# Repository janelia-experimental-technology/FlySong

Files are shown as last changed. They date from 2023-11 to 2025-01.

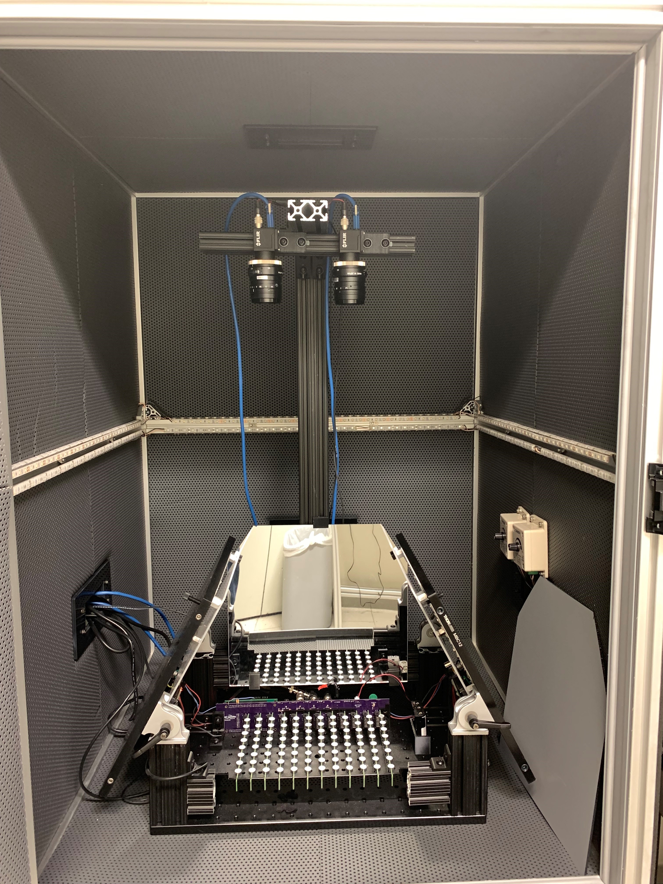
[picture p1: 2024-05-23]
PHOTOS/RIG WITH RGB/LEDrigall.jpg

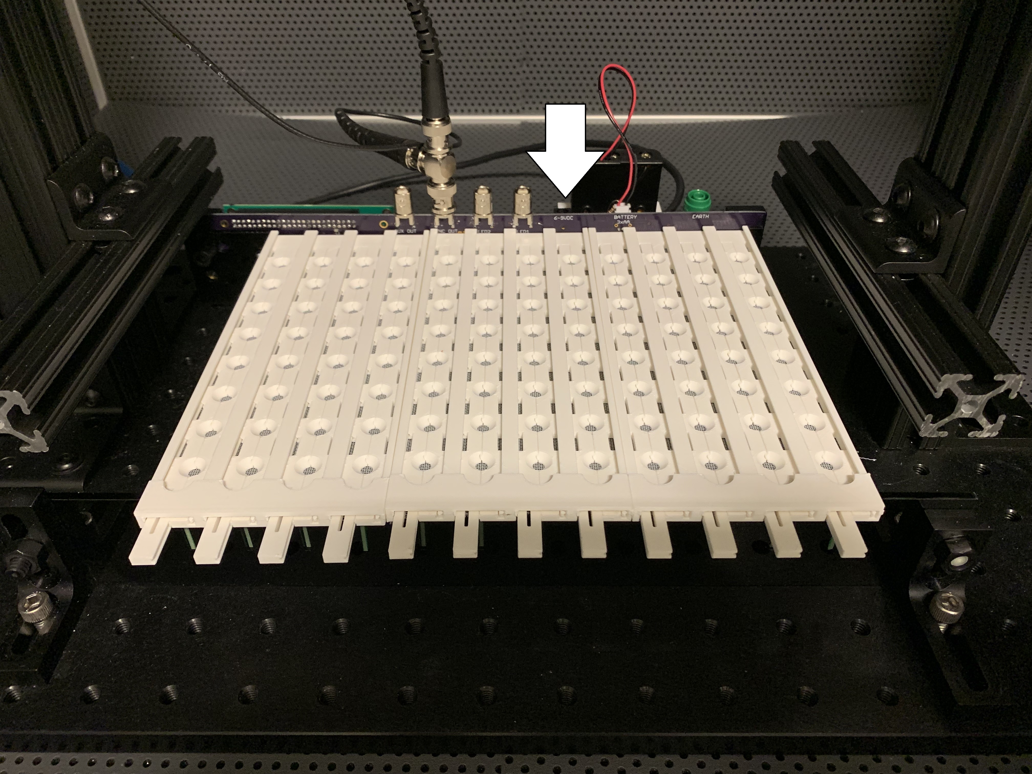
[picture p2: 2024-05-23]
PHOTOS/6V conector.jpg

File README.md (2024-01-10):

# FlySong
Song Torrent: A 96 Chamber Fly Courtship Recording Array.

[Preprint](https://www.biorxiv.org/content/10.1101/2024.01.09.574712v1)

The 96 Chamber Array and open-source software was designed to provide high throughput acquisition of Drosophila fly courtship songs. 
Up to 96 separate chambers can be recorded simultaneously along with temperature data for each chamber. Chambers are designed as three 
arrays of 32 chambers each and have sliding partitions to allow loading of separated males and females. The chambers can be top loaded
using a mouth pipette with a sliding cover and loading hole or bottom loaded through a slit in the lower mesh. The latter method could
be used by auto-loading systems. Two optogenetic light drivers are provided and their timing and brightness can be controlled. A camera 
frame trigger ouput is also provided. The software allows any number and arrangement of chambers to be recorded. A separate time and 
brightness comma-separated variable (CSV) file defines the optogenetic light pattern. A separate CSV file can be used to predefine the
individual sample names and their chamber locations, or this information can be entered interactively in the GUI and saved. All data 
and metadata (lights, temperatures, camera triggers, audio, sample information, etc.) are saved to .WAV files

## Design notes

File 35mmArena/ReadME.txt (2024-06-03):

35mmArena

The 35mm Arena provides a circular, 35mm diameter, fly arena with recording capbilities. Seven microphones provide coverage for the entire arena. The circuitry is the same design used in the 96 channel FlySong rig, so one 35mm arena can be plugged into one of the 96 channel backplane connectors and use the same software to record audio.

Boards available at Circuithub:

3MIC_backplaneREVA
3MIC_ximpedanceREVB

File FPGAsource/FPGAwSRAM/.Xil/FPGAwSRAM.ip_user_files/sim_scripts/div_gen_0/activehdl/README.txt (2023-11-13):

################################################################################
# Vivado (TM) v2017.1 (64-bit)
#
# README.txt: Please read the sections below to understand the steps required to
#             run the exported script and information about the source files.
#
# Generated by export_simulation on Sun May 14 15:33:39 -0400 2017
#
################################################################################

1. How to run the script:-

From the shell prompt in the current directory, issue the following command:-

./div_gen_0.sh

This command will launch the 'compile', 'elaborate' and 'simulate' functions
implemented in the script file for the 3-step flow. These functions are called
from the main 'run' function in the script file. For IES this command will
launch the 'execute' function for the single-step flow.

The 'run' function first executes 'setup' function the purpose of which is to
create simulator specific setup files, create design library mappings and library
directories and copy 'glbl.v' from the Vivado software install location into the
current directory.

The 'setup' function is also used for removing the simulator generated data in
order to reset the current directory to the original state when export_simulation
was launched. This generated data can be removed by specifying the '-reset_run'
switch to the './div_gen_0.sh' script.

./div_gen_0.sh -reset_run

To keep the generated data from the previous run but regenerate the setup files
and library directories, use the -noclean_files switch.

./div_gen_0.sh -noclean_files

For more information on the script, please type './div_gen_0.sh -help'.

2. Additional design information files:-

export_simulation generates following additional files that can be used for
fetching the design files information or for integrating with external custom
scripts.

Name   : file_info.txt
Purpose: This file contains detail design file information based on the compile
         order when export_simulation was executed. The file contains information
         about the file type, name, whether belongs to IP, associated library and
         the file path.

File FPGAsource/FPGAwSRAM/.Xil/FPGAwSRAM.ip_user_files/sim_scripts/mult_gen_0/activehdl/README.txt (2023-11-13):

################################################################################
# Vivado (TM) v2017.1 (64-bit)
#
# README.txt: Please read the sections below to understand the steps required to
#             run the exported script and information about the source files.
#
# Generated by export_simulation on Sun May 14 15:33:40 -0400 2017
#
################################################################################

1. How to run the script:-

From the shell prompt in the current directory, issue the following command:-

./mult_gen_0.sh

This command will launch the 'compile', 'elaborate' and 'simulate' functions
implemented in the script file for the 3-step flow. These functions are called
from the main 'run' function in the script file. For IES this command will
launch the 'execute' function for the single-step flow.

The 'run' function first executes 'setup' function the purpose of which is to
create simulator specific setup files, create design library mappings and library
directories and copy 'glbl.v' from the Vivado software install location into the
current directory.

The 'setup' function is also used for removing the simulator generated data in
order to reset the current directory to the original state when export_simulation
was launched. This generated data can be removed by specifying the '-reset_run'
switch to the './mult_gen_0.sh' script.

./mult_gen_0.sh -reset_run

To keep the generated data from the previous run but regenerate the setup files
and library directories, use the -noclean_files switch.

./mult_gen_0.sh -noclean_files

For more information on the script, please type './mult_gen_0.sh -help'.

2. Additional design information files:-

export_simulation generates following additional files that can be used for
fetching the design files information or for integrating with external custom
scripts.

Name   : file_info.txt
Purpose: This file contains detail design file information based on the compile
         order when export_simulation was executed. The file contains information
         about the file type, name, whether belongs to IP, associated library and
         the file path.

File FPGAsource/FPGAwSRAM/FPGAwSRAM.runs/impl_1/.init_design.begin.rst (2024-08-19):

<?xml version="1.0"?>
<ProcessHandle Version="1" Minor="0">
    <Process Command=".planAhead." Owner="sawtelles" Host="SAWTELLES-LW2" Pid="19712">
    </Process>
</ProcessHandle>

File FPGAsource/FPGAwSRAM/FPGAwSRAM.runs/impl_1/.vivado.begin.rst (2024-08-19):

<?xml version="1.0"?>
<ProcessHandle Version="1" Minor="0">
    <Process Command="vivado.bat" Owner="sawtelles" Host="SAWTELLES-LW2" Pid="18224" HostCore="20" HostMemory="033947738112">
    </Process>
</ProcessHandle>

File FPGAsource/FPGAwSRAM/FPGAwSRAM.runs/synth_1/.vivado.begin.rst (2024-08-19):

<?xml version="1.0"?>
<ProcessHandle Version="1" Minor="0">
    <Process Command="vivado.bat" Owner="sawtelles" Host="SAWTELLES-LW2" Pid="8160" HostCore="20" HostMemory="033947738112">
    </Process>
</ProcessHandle>

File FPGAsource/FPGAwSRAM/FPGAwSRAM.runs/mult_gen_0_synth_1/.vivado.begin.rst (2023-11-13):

<?xml version="1.0"?>
<ProcessHandle Version="1" Minor="0">
    <Process Command="vivado.bat" Owner="sawtelles" Host="SAWTELLES-LW1" Pid="9176">
    </Process>
</ProcessHandle>

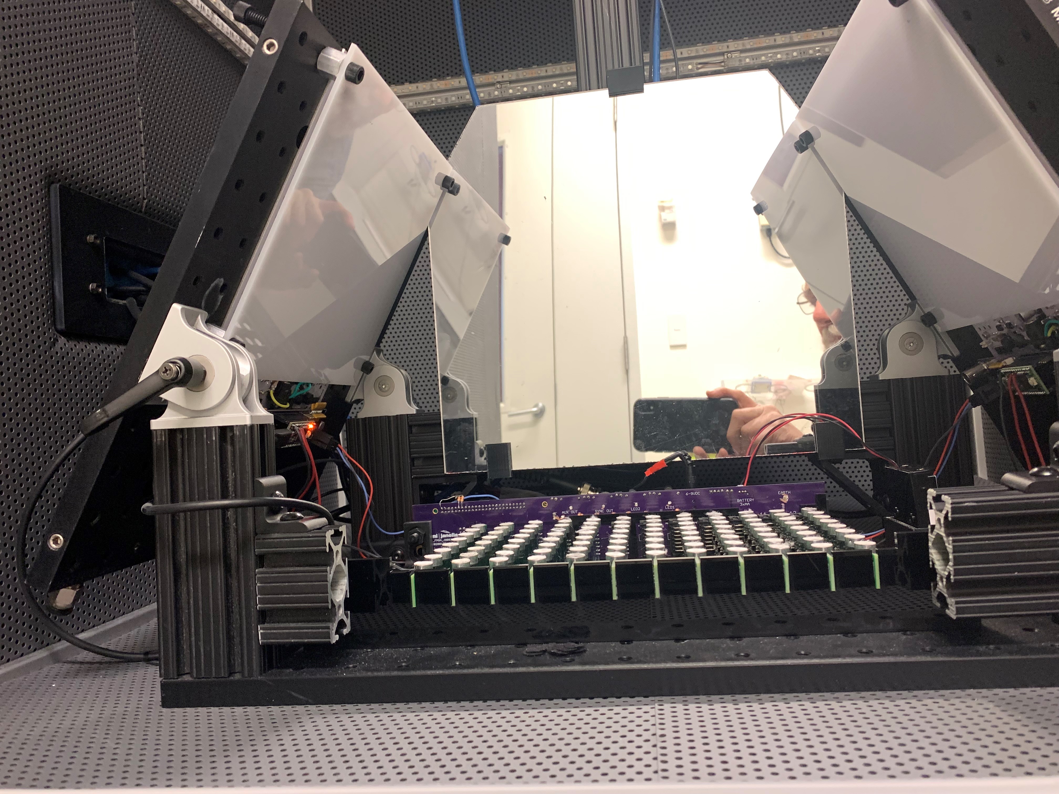
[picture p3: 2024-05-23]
PHOTOS/RIG WITH RGB/LEDrigfront.jpg

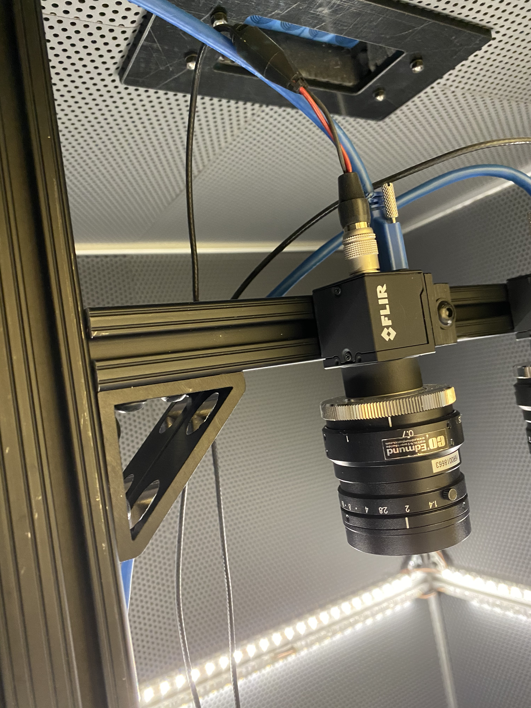
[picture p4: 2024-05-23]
PHOTOS/camera.jpg

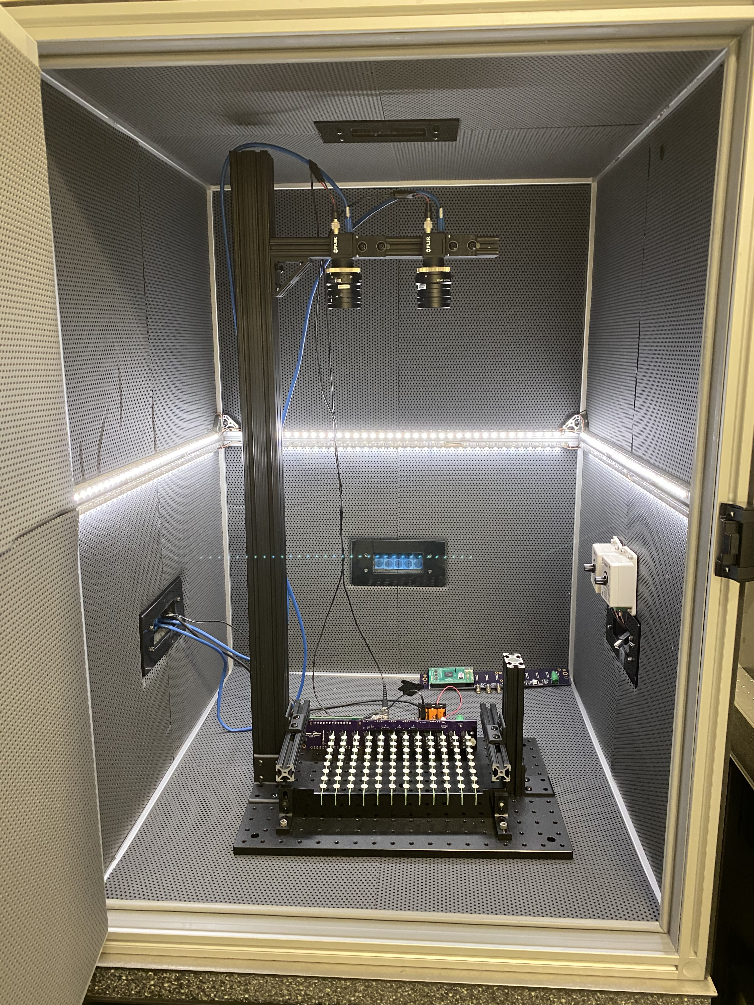
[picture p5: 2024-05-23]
PHOTOS/rig.jpg

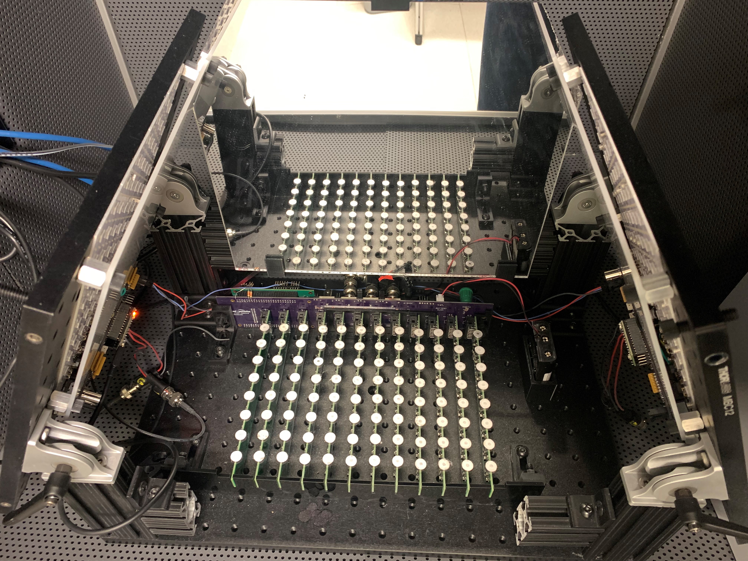
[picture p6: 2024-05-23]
PHOTOS/RIG WITH RGB/LEDrigFromRear.jpg

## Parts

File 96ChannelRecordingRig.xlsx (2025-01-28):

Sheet: Top Level
Top level | Fly Courtship 96 Channel Recording Rig
Quantity | Function | Item | Manufacturer | Man. Part Number | Vendor | Vendor Part Number | Cost | Total Cost | Notes
1 | Breadboard | Aluminum Breadboard 12" x 18" x 1/2", 1/4"-20 Taps | Thorlabs | MB1218 | (same) | (same) | $188.00 | $188.00
4 | backplane to breadboard bracket | Slim Right-Angle Bracket with Counterbored Slots | Thorlabs | AB90H | (same) | (same) | $27.04 | $108.16 | OR - use backplaneBracket 3-D print
 |  | Backplane Bracket | 3-D print |  |  | backplaneBracket |  | $0.00 | alternate to AB90H
1 | Fasten bracketss to breadboard | Black-oxide stainless steel screw 1/4-20 x 5/8 |  |  | McMaster-Carr | 96006A705 | $8.05 | $8.05 | pkg of 25 - need 4
1 | Fasten backplane and board supports to brackets | Nylon Socket Head Screws, black, 1/4"-20 Thread Size, 7/8" Long |  |  | McMaster-Carr | 95868A745 | $9.57 | $9.57 | pkg of 100, need 4
1 | Fasteners for nylon screws | Nylon Hex Nut, 1/4"-20 Thread Size |  |  | McMaster-Carr | 95868A743 | $9.65 | $9.65 | pkg of 100 need 4
1 | Camera Support Post | T-Slotted Framing, Quad Rail, Black 2" High x 2" Wide, Solid |  |  | McMaster-Carr | 47065T678 | $59.62 | $59.62 | Only for standard (non-RGB-IR) setup
2 | Camera Post Brackets | T-Slotted Framing, Black Open Gusset Corner Bracket for 2" High Rail, 2" Long |  |  | McMaster-Carr | 3136N183 | $25.34 | $50.68
1 | Camera Mounting Bar | T-Slotted Framing, Double Six Slot Rail, Black, 2" High x 1" Wide, Solid |  |  | McMaster-Carr | 47065T495 | $17.24 | $17.24 | 12" length
1 | Chamber supports | MicrophoneChamberSupports_J007968.dxf | Janelia | J007968 | McMaster-Carr | 8505K741 | $7.71 | $7.71 | Laser cut from 1/8" acrylic
1 | Battery Box | BatteryBox_J007969.stl | Janelia | J007969 |  |  | $0.00 | $0.00 | 3D print
1 | Battery Holder | BATT HOLDER AA 3 CELL WIRE LEADS | Keystone Electronics | 2465CN | Digi-Key | 36-2465CN-ND | $2.20 | $2.20
1 | Charger with 4 batteries | BATT CHARGER WALL MT 300MA/150MA | Energizer Battery Company | CHVCMWB-4 | Digi-Key | N732-ND | $18.46 | $18.46
8 | Batteries | BATTERY NIMH 1.2V 2.3AH AA 1=8PK | Energizer Battery Company | NH15BP-8 | Digi-Key | N730-ND | $3.98 | $31.84 | optional, gives 4 changes of batteries
1 | FPGA Board | XC7A15T Xilinx Artix-7, 32 Mb SPI flash | Opal Kelly | XEM7001 | Opal Kelly | (same) | $199.95 | $199.95
1 | Power Supply | AC/DC WALL MNT ADAPTER 6V 200MA | Triad Magnetics | WDU6-200 | Digi-Key | 237-2322-ND | $8.38 | $8.38
1 | Headers for FPGA board | Female header connectors for XEM3/6/7001 | Opal Kelly | HDRM-XEM3001 | Opal Kelly | (same) | $10.00 | $10.00 | Solder to bottom of XEM7001
3 | Fly Chamber Assembly | FLY CHAMBER ASSEMBLY TAB |  |  |  |  |  | $0.00 | 3 pieces
1 | Backplane interconnection board | BACKPLANE PCB ASSEMBLY TAB |  | 12_BCKPLN_FPGA_J007922REVA |  |  | $99.49 | $99.49
12 | Microphone Amplifiers/Converters | MICROPHONE PCB ASSEMBLY TAB |  | 8MIC_ximpedance_J007901A |  |  | $212.14 | $2545.68 | 12 pieces
2 | Camera Assemblies | CAMERA ASSEMBLY TAB |  |  |  |  | $3158.38 | $6316.76
 | Opal Kelley FPGA Drivers |  | Opal Kelly | FrontPanelUSB-DriverOnly-5.3.0.exe |  |  |  | $0.00
 | Fly Song Software |  | Janelia | FlySong.zip |  |  |  | $0.00
1 | RGB_IR Lighting | RGB_IR LIGHTING TAB |  |  |  |  | $2189.02 | $2189.02 | optional if optogenic and/or IR lighting is needed
 | TOTAL |  |  |  |  |  |  | $11880.46

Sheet: Camera Assembly
Camera Assembly
Quantity | Value | Device | Manufacturer | Manufacturer PN | Vendor | Vendor PN | $ea | $Total | Notes
2 | Blackfly S Monochrome | Camera | FLIR | BFS-U3-200S6M-C | Edmund Optics | 11-521 | $850.00 | $1700.00
2 | 50mm 1" Sensor Format C-Mount | Lens |  |  | Edmund Optics | 63-248 | $595.00 | $1190.00
2 | Type-A to Micro-B, USB 3.1 Locking Cable, 3m | USB Cable |  |  | Edmund Optics | 86-770 | $52.00 | $104.00
2 | Blackfly S/Blackfly 6-pin GPIO Hirose Connector Cable, 1m | Trigger Cable |  |  | Edmund Optics | 88-064 | $67.00 | $134.00
2 | 5.9" (149.86mm) BNC, Male Plug To Wire Lead Test Lead 500VAC | BNC Assembly | Pomona | 4970 | Digi-Key | 501-1031-ND | $15.19 | $30.38
 | Trigger Cable Assembly Instructions |  | Janelia | TriggerCable.sch |  |  |  |  | Instructions to wire cable
 | TOTAL |  |  |  |  |  |  | $3158.38

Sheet: RGB-IR Lighting
 |  |  |  |  |  |  |  |  |  | 2x2 Framing |  | 1x2 Framing
Quantity | Value | Device | Manufacturer | Manufacturer Part Number | Vendor | Vendor PN | $ea | $ total | Notes | Length | Total Length | Length | Total Length | $ea | $Total | DNI | Substitutions Allowed | Substitute Manufacturer | Substitute Part Number
2 | 7x7 RGB-IR LED Board | Janelia LED Board |  |  |  |  | $298.76 | $597.51
2 | 7x7 controller |  |  |  |  |  | $90.11 | $180.22
2 | 12" x 12" Breadboard | Aluminum Breadboard 12" x 12" x 1/2", 1/4"-20 Taps | Thorlabs | MB12 |  |  | $172.40 | $344.80 | MBC12 if active cooling needed
54 | Thread adapter | Adapter with Internal 4-40 Threads and External 1/4"-20 Thread | Thorlabs | AE4E25E |  |  | 4.97 | $268.38
2 | Diffuser |  | ePlastics | 2447 White 1/18" thick |  |  |  | $0.00 | Laser cut using DiffuserFlySongRGB.dxf
4 | Locking Pivot | T-Slotted Framing, Locking Inline/Perpendicular Pivot for 2" Double/Quad | McMaster-Carr | 47065T381 |  |  | $49.83 | $199.32
2 | Vertical Post-front | T-Slotted Framing, Double Six Slot Rail, Black, 2" High x 1" Wide, Solid | McMaster-Carr | 47065T495 |  |  |  | $0.00 | Cut to 4.5" length |  |  | 4.5 | 9
2 | Vertical Post-rear | T-Slotted Framing, Double Six Slot Rail, Black, 2" High x 2" Wide, Solid | McMaster-Carr | 47065T678 |  |  |  | $0.00 | Cut to 4.5" length | 4.5 | 9
3 | 1x2 Right Angle Bracket | T-Slotted Framing, Black Corner Bracket, 1" Long for 2" High Double/Quad Rail | McMaster-Carr | 47065T474 |  |  | $16.60 | $49.80
1 | Cross Beam | T-Slotted Framing, Double Six Slot Rail, Black, 2" High x 2" Wide, Solid | McMaster-Carr | 47065T678 |  |  |  | $0.00 | Cut to 14" length | 14 | 14
1 | Camera Post | T-Slotted Framing, Double Six Slot Rail, Black, 2" High x 2" Wide, Solid | McMaster-Carr | 47065T695 |  |  |  | $0.00 | Cut to 28" length | 28 | 28
1 | Camera Beam | T-Slotted Framing, Double Six Slot Rail, Black, 2" High x 1" Wide, Solid | McMaster-Carr | 47065T695 |  |  |  | $0.00 | Cut to 7" length |  |  | 7 | 7
1 | Camera Mount Beam | T-Slotted Framing, Double Six Slot Rail, Black, 2" High x 1" Wide, Solid | McMaster-Carr | 47065T496 |  |  |  | $0.00 | Cut to 12" length |  |  | 12 | 12
6 | 2x2 Brackets | T-Slotted Framing, Black Open Gusset Corner Bracket for 2" High Rail, 2" Long | McMaster-Carr | 3136N183 |  |  | $25.34 | $152.04
2 | Mirrors | Acrylic Plastic Damage-Resistant Mirror, 12" High x 12" Wide x 1/8" Thick, Screw Mount | McMaster-Carr | 3052K19 |  |  | $25.00 | $50.00 | Laser Cut using FlySongRGBMirror.dxf
2 | Front Miror Support | T-Slotted Framing, Double Six Slot Rail, Black, 2" High x 1" Wide, Solid | McMaster-Carr | 47065T495 |  |  |  | $0.00 | Cut to 2" length |  |  | 2 | 4
2 | Mirror Support Brackets | Black Corner Bracket, 1" Long, for 1" High Rail T-Slotted Framing | McMaster-Carr | 47065T831 |  |  | $9.71 | $19.42
4 | Diffuser Standoff | Male-Female Threaded Hex Standoff, Aluminum, 1/2" Hex Size, 1" Long, 1/4"-20 Thread Size | McMaster-Carr | 93505A197 |  |  |  | $0.00
2 | Rear Mirror Supports | 3-D printed |  | T-Slotted Mirror Support.stl |  |  |  | $0.00 | 3-D print
2 | Serial cable assembly | RGB Interconnect Cable |  |  |  |  |  | $0.00
2 | Power Supply | Desktop AC Adapters, Level VI, Desktop, 100 Watt, 90-264VAC Input, 28VDC Output, | Cincon | TRH100A280-12E13-Level-VI |  |  | $49.41 | $98.82
 |  |  |  |  |  |  |  | $0.00 | Total length |  | 51 |  | 32
 |  |  |  |  |  |  |  | $0.00
1 | TOTAL length needed | T-Slotted Framing, Double Six Slot Rail, Black, 2" High x 2" Wide, Solid | McMaster-Carr | 47065T678 |  |  | $96.65 | $96.65 |  |  | 51
3 | TOTAL length needed | T-Slotted Framing, Double Six Slot Rail, Black, 2" High x 1" Wide, Solid | McMaster-Carr | 47065T495 |  |  | $44.02 | $132.06 |  |  |  |  | 32
 |  |  |  |  |  | TOTAL |  | $2189.02

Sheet: Fly Chamber Assembly
Fly Chamber Assembly
Quantity | Function | Item | Manufacturer | Man. Part Number | Vendor | Vendor Part Number | Cost | Total Cost | Notes | Manufacturing File
3 | Fly Chambers (4x8) | Fly Chamber Base, 32 chambers | Janelia | Chamber_4x8_J007977 |  |  |  |  | 3D Print | Chamber_4x8_J007977.STL
12 | Chamber -moving half | Fly Chamber Sliding part, 8 chambers | Janelia | ChamberSlide_J007974 |  |  |  |  | 3D Print | ChamberSlide_J007974.STL
2 | Loading Slide | Fly Chamber Fly loader | Janelia | Loader_J007975 | McMaster-Carr | 8560K171 (raw material) | 5.61 |  | laser cut, 1/16" clear acrylic | Loader_J007975.dxf
12 | Run Slide | Fly Chamber Run Slide cover | Janelia | RunSlide_J007976 | McMaster-Carr | 8560K171 (raw material) | 5.61 |  | laser cut, 1/16" clear acrylic | RunSlide_J007976.dxf
1 | Plastic Mesh | Moisture-Resistant Plastic Mesh, 34 x 34 Mesh Size, 53" Wide |  |  | McMaster-Carr | 9318T21 | 20.21 |  | heat melt to bottom of chamber body

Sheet: Backplane Assembly
Backplane | 12_BCKPLN_FPGA_J007922REVA
Quantity | Value | Device | Designators | Manufacturer | Manufacturer Part Number | Vendor | Vendor Part Number | $ea | $Total | DNI | Substitutions Allowed | Substitute Manufacturer | Substitute Part Number
1 |  | CONN BANANA JACK SOLDER GREEN | P13 | Cal Test Electronics | CT3151-5 | Digi-Key | BKCT3151-5-ND | $2.05 | $2.05 |  | yes
1 |  | CONN HEADER R/A 3POS 2MM | J1 | Keystone Electronics | 975 | Digi-Key | 36-975-ND | $1.12 | $1.12 |  | yes
1 | header | CONN HEADER VERT 4POS 2.54MM | JP1 | Wurth Electronics Inc. | 61300411121 | Digi-Key | 732-5317-ND | $0.18 | $0.18 |  | yes
1 |  | CONN PWR JACK 2X5.5MM SOLDER | J2 | CUI Inc. | PJ-002AH-SMT-TR | Digi-Key | CP-002AHPJCT-ND | $1.44 | $1.44 |  | yes
10 | 0.1 | CAPS0603S | C1 C2 C3 C4 C5 C6 C7 C8 C11 C12 | KEMET | C0603C104K5RACTU | DigiKey | 399-5089-1-ND | $0.21 | $2.10 |  | yes
2 | 2G240 | IC BUFFER INVERT 5.5V SM8 | U7 U8 | Texas Instruments | SN74LVC2G240DCTR | Digi-Key | 296-15588-1-ND | $0.72 | $1.44 |  | yes
2 | 10 | CAP CER 10UF 16V X7R 1210 | C9 C10 | KEMET | C1210C106K4RACTU | Digi-Key | 399-8225-1-ND | $0.65 | $1.30 |  | yes
8 | 49.9 | RES 49.9 OHM 1% 1/8W 0805 | R3 R4 R6 R7 R8 R9 R10 R11 | Stackpole Electronics Inc | RMCF0805FT49R9 | Digi-Key | RMCF0805FT49R9CT-ND | $0.10 | $0.80 |  | yes
3 | 74LVC1G17DBV | IC BUF NON-INVERT 5.5V SOT23-5 | U1 U2 U3 | Texas Instruments | SN74LVC1G17QDBVRQ1 | Digi-Key | 296-32300-1-ND | $0.36 | $1.08 |  | yes
2 | 191 | RES 100 OHM 1% 1/8W 0805 | R1 R5 | Stackpole Electronics Inc | RMCF0805FT191R | Digi-Key | RMCF0805FT191RCT-ND | $0.10 | $0.20 |  | yes
1 | 200K | RES 200K OHM 1% 1/8W 0805 | R13 | Stackpole Electronics Inc | RMCF0805FT200K | Digi-Key | RMCF0805FT200KCT-ND | $0.10 | $0.10 |  | yes
1 | 100K | RES 100K OHM 1% 1/8W 0805 | R13 | Stackpole Electronics Inc | RMCF0805FT100K | Digi-Key | RMCF0805FT100KCT-ND | $0.10 | $0.10 |  | yes
4 | BNC | CONN BNC JACK STR 50 OHM PCB | J3 J4 J5 J6 | TE Connectivity AMP Connectors | 5227699-3 | Digi-Key | A32249-ND | $4.77 | $19.08 |  | yes
12 | CON14ST2X7_PLUG | CONN HDR 14POS 0.1 GOLD PCB | P1 P2 P3 P4 P5 P6 P7 P8 P9 P10 P11 P12 | Sullins Connector Solutions | SFH11-PBPC-D07-ST-BK | Digi-Key | S9195-ND | $0.91 | $10.92 |  | yes
1 | LP2950CDT-5.0 | IC REG LINEAR 5V 100MA TO252-3 | U6 | Texas Instruments | LP2950CDT-5.0 | Digi-Key | LP2950CDT-5.0/NOPB-ND | $1.28 | $1.28 |  | yes
1 | MAX931 | IC COMP SNGL LOW PWR W/REF 8SOIC | U2 | Maxim Integrated | MAX931ESA+T | Digi-Key | MAX931ESA+TCT-ND | $5.40 | $5.40 |  | yes
2 | TLP176G(F) | SSR RELAY SPST-NO 2A 0-40V | U5 U9 | Toshiba Semiconductor and Storage | TLP241A(TP1,F | Digi-Key | TLP241A(TP1FCT-ND | $2.18 | $4.36 |  | yes
2 | header 2x25 | CONN HDR 50POS 0.1 GOLD PCB | M1 | Sullins Connector Solutions | PPPC252LFBN-RC | Digi-Key | S7128-ND | $2.64 | $5.28 |  | yes
1 | header 2x10 | CONN HDR 20POS 0.1 GOLD PCB | M1 | Sullins Connector Solutions | PPPC102LFBN-RC | Digi-Key | S6106-ND | $1.26 | $1.26 |  | yes
1 | PCB | Bare Printed Circuit Board |  | Janelia | 12_BCKPLN_FPGA_J007922REVB | Oshpark | https://oshpark.com/shared_projects/Ftha9rSP | $40.00 | $40.00
 |  |  |  |  |  |  | TOTAL |  | $99.49

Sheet: Microphone Assembly
Microphone |  | 8MIC_ximpedance_J007901A
Quantity | Value | Device | Designators | Manufacturer | Manufacturer Part Number | Vendor | Vendor Part Number | $ea | $Total | DNI | Substitutions Allowed | Substitute Manufacturer | Substitute Part Number
8 | 0 | RESISTOR_SM0603S | R58 R59 R60 R61 R62 R63 R65 R66 | Vishay Dale | CRCW06030000Z0EAHP | DigiKey | 541-0.0SBCT-ND | $0.16 | $1.28 |  | yes
11 | 0.1 | CAPS0603S | C1 C2 C3 C4 C5 C6 C7 C8 C87 C88 C98 | KEMET | C0603C104K5RACTU | DigiKey | 399-5089-1-ND | $0.21 | $2.31 |  | yes
9 | 0.01 NPO | CAP CER 10000PF 25V C0G/NP0 0603 | C10 C19 C20 C21 C22 C23 C24 C25 C26 | KEMET | C0603C103J3GACTU | DigiKey | 399-7838-1-ND | $0.45 | $4.05 |  | yes
~~0~~ | ~~DNI~~ | ~~CAPS0603S~~ | ~~C89 C90 C91 C92 C93 C94 C95 C96~~ |  |  |  |  |  | $0.00 | DNI
8 | 0.22 | 0.22µF Film Capacitor 12V 16V Acrylic, Metallized 1206 | C43 C44 C45 C46 C47 C48 C49 C50 | Cornell Dubilier | FCA1206C224M-H1 | DigiKey | 338-2774-1-ND | $0.78 | $6.24 |  | yes
16 | 0.047 | CAP CER 0.047UF 25V NP0 0805 | C52 C53 C54 C55 C56 C57 C58 C59 C79 C80 C81 C82 C83 C84 C85 C86 | KEMET | C0805C473K3GAC7800 | DigiKey | 399-14611-1-ND | $0.94 | $15.04 |  | yes
8 | 2.2 | CAP FILM 2.2UF 20% 25VDC 1210 | C35 C36 C37 C38 C39 C40 C41 C42 C77 | Rubycon | 25MU225MB23225 | DigiKey | 1189-2524-1-ND | $5.44 | $43.52 |  | yes
4 | 10 | CAP CER 10UF 25V X5R 0805 | C9 C51 C78 C97 | Murata | GRM21BR61E106KA73L | DigiKey | 490-5523-1-ND | $0.54 | $2.16 |  | yes
8 | 330p | CAP CER 330PF 50V C0G/NP0 0805 | C62 C64 C65 C66 C67 C68 C69 C70 | KEMET | C0805C331J1GACTU | DigiKey | 399-1131-1-ND | $0.21 | $1.68 |  | yes | AVX | 08055A331JAT2A
8 | 29K4 | RES SMD 29.4K OHM 1% 1/10W 0603 | R34 R35 R36 R37 R38 R39 R40 R41 | Susumu | RR0816P-2942-D-46C | DigiKey | RR08P29.4KDCT-ND | $0.10 | $0.80 |  | yes
25 | 49K9 | RES 49.9K OHM 0.1% 1/8W 0603 | R1 R18 R19 R20 R21 R22 R23 R24 R25 R26 R27 R28 R29 R30 R31 R32 R33 R43 R44 R45 R47 R48 R50 R51 R53 | Vishay Dale | TNPW060349K9BEEA | DigiKey | TNP49.9KAACT-ND | $0.59 | $14.75 |  | yes
8 | 4K02 | RES 4.02K OHM 0.1% 1/8W 0603 | R4 R5 R6 R7 R8 R9 R15 R17 | Vishay Dale | TNPW06034K02BEEA | DigiKey | TNP4.02KAACT-ND | $0.59 | $4.72 |  | yes
16 | 1200p | 1200pF Film Capacitor 100V Polyester, | C27 C28 C29 C30 C31 C32 C33 C34 C60 C61 C71 C72 C73 C74 C75 C76 | Panasonic | ECW-U1122JX5 | DigiKey | PCF1349CT-ND | $0.68 | $10.88 |  | yes
1 | 2514-5 | 14 Positions Header, Shrouded Connector 0.100" (2.54mm) Through Hole, Right Angle Gold | J1 | 3M | N2514-5002-RB | DigiKey | MHE14K-ND | $2.07 | $2.07
1 | LP3985 | IC REG LINEAR 3.3V 150MA SOT23-5 | U9 | Texas Instruments | LP3985IM5-3.3/NOPB | DigiKey | LP3985IM5-3.3/NOPBCT-ND | $0.66 | $0.66
1 | LTC1867L | 16 Bit Analog to Digital Converter 8 Input 1 SAR 16-SSOP | U18 | LT | LTC1867LACGN#PBF | DigiKey | LTC1867LACGN#PBF-ND | $18.47 | $18.47
8 | OPA2376 | General Purpose Amplifier 1 Circuit Rail-to-Rail 8-uMAX | U10 U11 U12 U13 U14 U15 U16 U17 | TI | OPA2376AIDGKR | DigiKey | 296-22630-1-ND | $2.29 | $18.32
8 | TMP05/06 | SENSOR DIGITAL -40C-150C SOT23-5 | U1 U2 U3 U4 U5 U6 U7 U8 | TI | TMP05BRTZ-500RL7 | DigiKey | TMP05BRTZ-500RL7CT-ND | $2.73 | $21.84
8 | 133K | RES SMD 133K OHM 1% 1/8W 0603 | R42 R46 R49 R52 R54 R55 R56 R57 | TE | CPF0603F133KC1 | DigiKey | A102212CT-ND | $0.18 | $1.44 |  | yes
9 | 47uF | CAP TANT 47UF 10% 10V 1206 | C11 C12 C13 C14 C15 C16 C17 C18 C63 | AVX Corporation | F931A476KAA | DigiKey | 478-8223-1-ND | $0.81 | $7.29 |  | yes
8 | 499 | RES 499 OHM 1% 1/8W 0603 | R2 R3 R10 R11 R12 R13 R14 R16 | Stackpole Electronics Inc | RNCP0603FTD499R | DigiKey | RNCP0603FTD499RCT-ND | $0.10 | $0.80 |  | yes
1 | 10 | RES 10 OHM 1% 1/8W 0603 | R64 | Stackpole Electronics Inc | RNCP0603FTD10R0 | DigiKey | RNCP0603FTD10R0CT-ND | $0.10 | $0.10 |  | yes
1 |  | Bare Printed Circuit Board |  | Janelia | 8MIC_ximpedance_J007901D | Oshpark | https://oshpark.com/shared_projects/GOl5GIfq | $15.00 | $15.00 |  |  | Other PCB vendors can be used
8 |  | Multilayer Ceramic Capacitor, 0.1 uF, 50 V, ± 10%, X7R, 0805 | C1 C2 C3 C4 C5 C6 C7 C8 | Samsung | CL21B104KBCNNNC | DigiKey | 1276-1003-1-ND | $0.10 | $0.80
8 | MIC-CUI | MIC COND ANALOG NOISE CAN -47DB | M1 M2 M3 M4 M13 M14 M15 M16 | CUI Inc. | CMP-5247TF-K | DigiKey | 102-1729-ND | $2.24 | $17.92 |  |  | Install after boards are assembled, using heat sink jig
Tools and fixtures |  |  |  |  |  |  |  |  | $212.14
 |  | Board alignment tool for microphone soldering |  | Janelia | mic_solder_station_holder_J007970.stl |  |  |  |  |  |  | 3D print, Place on microphone solder heat sink
 |  | Heat sink for microphone soldering |  | Janelia | mic_solder_station_J007971.ipt |  |  |  |  |  |  | Machine from aluminum

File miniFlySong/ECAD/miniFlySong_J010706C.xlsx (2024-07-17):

miniFlySong_J010706C.sch
Qty | Value | Device | Designators | Manufacturer | Man PN | Vendor | Vendor PN | $ea | $Total | Notes
1 |  | Connector Header Through Hole 4 position 0.100" (2.54mm) | GND | Würth Elektronik | 61300411121 | DK | 732-5317-ND | $0.19 | $0.19
1 |  | LED4045 red | BAD | Inolux | IN-S85CS5R | DK | 1830-IN-S85CS5RCT-ND | 0.27
1 |  | LED GREEN CLEAR SMD R/A | OK | Inolux | IN-S85CS5G | DK | 1830-IN-S85CS5GCT-ND | 0.36
2 | 0.1 | CAP CER 0.1UF 16V X7R 0603 | C1 C2 | KEMET | C0603C104K4RAC7082 | DK | 399-C0603C104K4RAC7082CT-ND | $0.10 | $0.20
1 | 74AUC1G17DBV | IC BUFF NON-INVERT 2.7 V SOT23-5 | U2 | Texas Instruments | SN74AUC1G17DBVR | DK | 296-12654-1-ND | $0.48 | $0.48
1 | 100K | RESISTOR_SM0805S | R1 | Bourns Inc. | CR0805AFX-1003EAS | DK | CR0805AFX-1003EASCT-ND | $0.10 | $0.10
3 | 191 | RESISTOR_SM0805S | R3 R5 R7 | Bourns Inc. | CR0805-FX-1910ELF | DK | 118-CR0805-FX-1910ELFCT-ND | $0.10 | $0.30
1 | 200K | RESISTOR_SM0805S | R2 | Bourns Inc. | CR0805-FX-2003ELF | DK | 118-CR0805-FX-2003ELFCT-ND | $0.10 | $0.10
1 | BNC | CONN BNC JACK STR 50 OHM PCB | J1 | TE | 5227222-1 | DK | A32246-ND | $4.32 | $4.32
1 | Battery Connector | CONN HEADER R/A 3POS 2MM | J2 | Keystone Electronics | 977 | DK | 36-977-ND | $1.22 | $1.22
1 | CON14ST2X7_PLUG | CONN HDR 14POS 0.1 GOLD PCB | P100 | Sullins Connector Solutions | SFH11-PBPC-D07-ST-BK | DK | S9195-ND | $0.91 | $0.91
1 | MAX931 | IC COMP SNGL LOW PWR W/REF 8SOIC | U1 | Maxim Integrated | MAX931ESA+T | DK | MAX931ESA+TCT-ND | $5.40 | $5.40
2 | PIN2F061.200 | CONN QC TAB 0.250 SOLDER | T1 T2 | TE | 726387-2 | DK | 726387-2-ND | $0.46 | $0.92
2 |  | CONN HDR 16POS 0.1 GOLD PCB | M1 | Sullins Connector Solutions | SFH11-PBPC-D08-ST-BK | DK | S9196-ND | $1.04
2 | TLP241A(TP1 | RELAY_SSRSMD4-GULL | U3 U4 | Toshiba | TLP241A(TP1,F |  | TLP241A(TP1FDKR-ND | $1.85
1 | Teensy 4.0 | TEENSY 4.0 (HEADERS) | M1 | SparkFun Electronics | DEV-16997 | DK | 1568-DEV-16997-ND | $28.50 |  | Plug in after board is complete

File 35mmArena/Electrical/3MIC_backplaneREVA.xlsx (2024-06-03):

Partlist exported from Z:/STERN/MICROPHONE_ARRAY/Emily35mm/ECAD/3MIC_backplaneREVA.sch at 5/15/2024 2:57 PM
Qty | Value | Device | Designators | Manufacturer | Man PN | Vendor | Vendor PN | $ea | $Total | Notes
3 |  | CONN HEADER VERT 10POS 2.54MM | J2 J3 J4 | 3M | 30310-6002HB | DigiKey | 30310-6002HB-ND
4 | 0.1 | CAPS0603S | C2 C3 C5 C7 | KEMET | C0603C104K5RACTU | DigiKey | 399-5089-1-ND | $0.21 | $0.84 |  | yes
3 | 10 | CAP CER 10UF 25V X5R 0805 | C1 C4 C6 | Murata | GRM21BR61E106KA73L | DigiKey | 490-5523-1-ND | $0.54 | $1.62 |  | yes
1 | 10R0 | RES 10 OHM 0.1% 1/10W 0805 | R1 | Stackpole | RNCS0805BKE10R0 | DigiKey | RNCS0805BKE10R0CT-ND
1 | 2514- | CONN HEADER VERT 14POS 2.54MM | J1 | 3M | 30314-6002HB | DigiKey | 30314-6002HB-ND
1 | LTC1867L | 16 Bit Analog to Digital Converter 8 Input 1 SAR 16-SSOP | U1 | LT | LTC1867LACGN#PBF | DigiKey | LTC1867LACGN#PBF-ND | $18.47 | $18.47
1 | M09LOCK | do not install | JP1

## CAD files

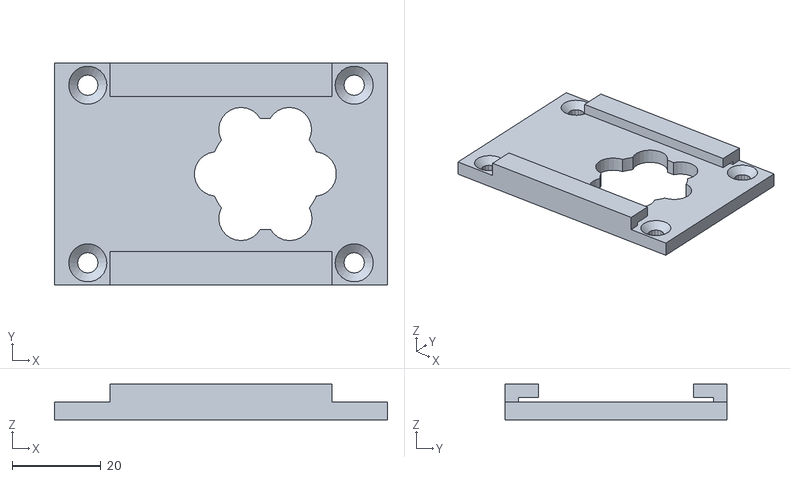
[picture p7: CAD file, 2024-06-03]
35mmArena/Mechanical/WHT-35mm lid support.stl
75.0 x 50.0 x 8.00

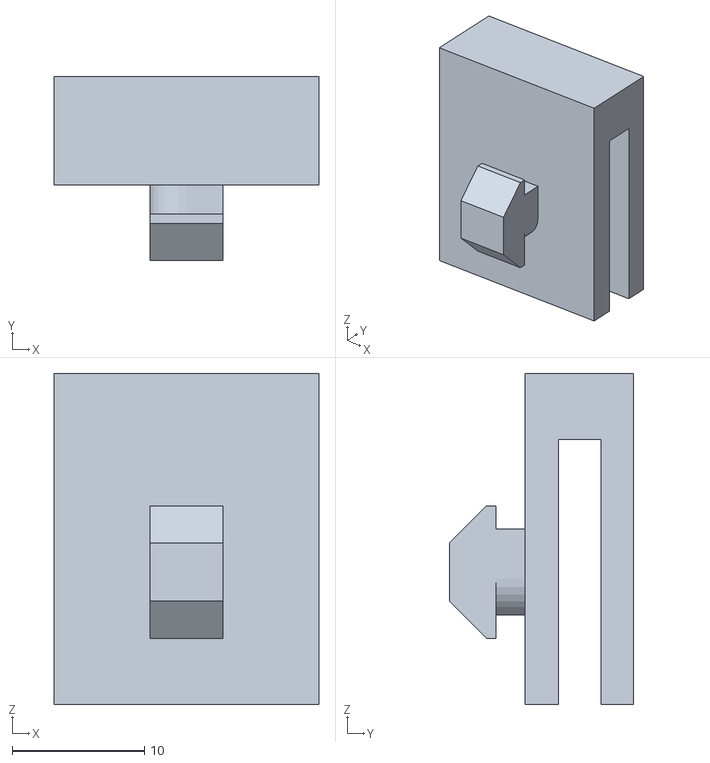
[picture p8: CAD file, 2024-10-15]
Mechanical/3DPrints/T-Slotted Mirror Support.stl
20.0 x 13.9 x 25.0

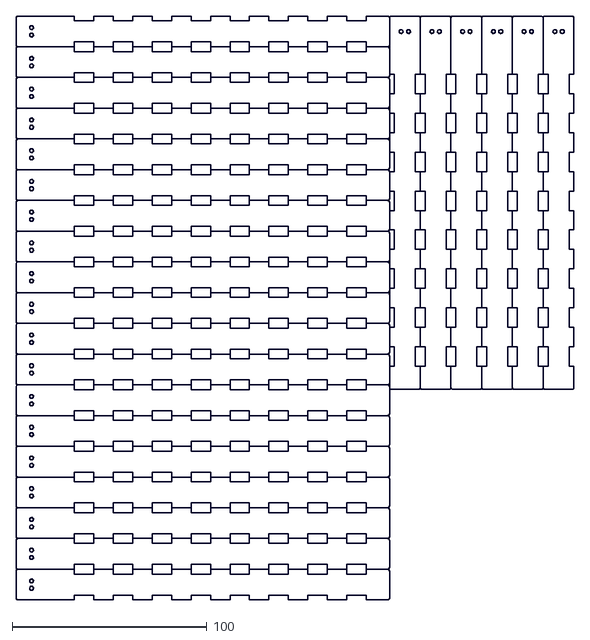
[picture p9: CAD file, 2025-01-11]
Mechanical/LaserCuts/LoadCover-12x12sheet.dxf
286.8 x 300.2

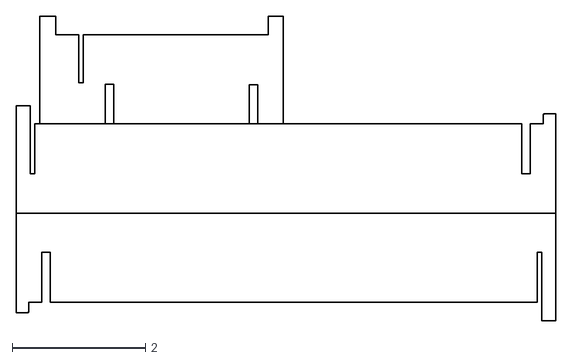
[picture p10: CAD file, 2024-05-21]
miniFlySong/MCAD/miniFlySongSupport.dxf
8.11 x 4.57

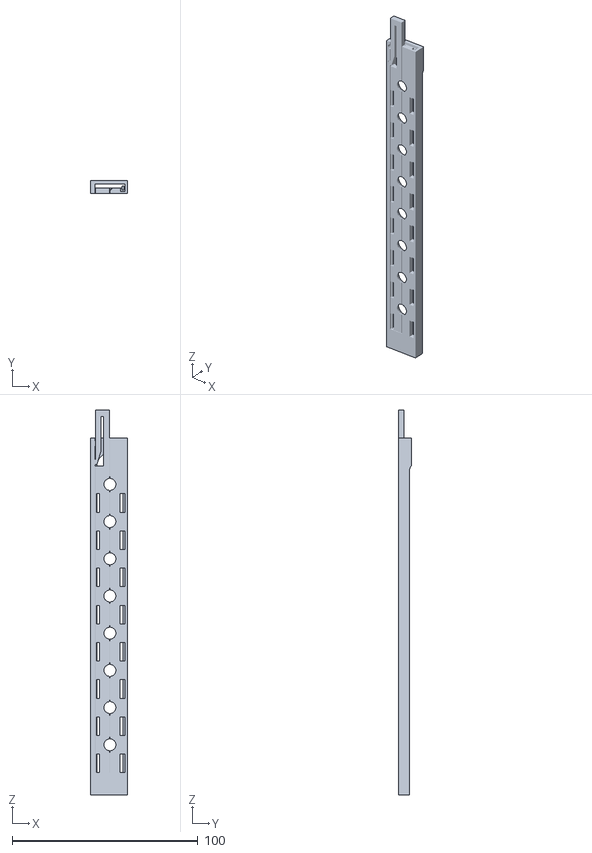
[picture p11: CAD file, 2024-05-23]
Mechanical/3DPrints/WHT_8Chamber_J009584D.stl
20.0 x 7.10 x 207.0

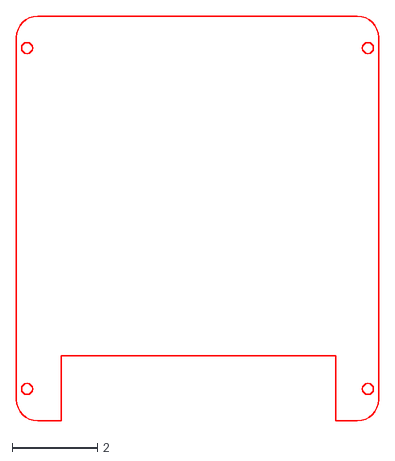
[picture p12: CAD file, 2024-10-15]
Mechanical/LaserCuts/DiffuserFlySongRGB.dxf
8.50 x 9.50

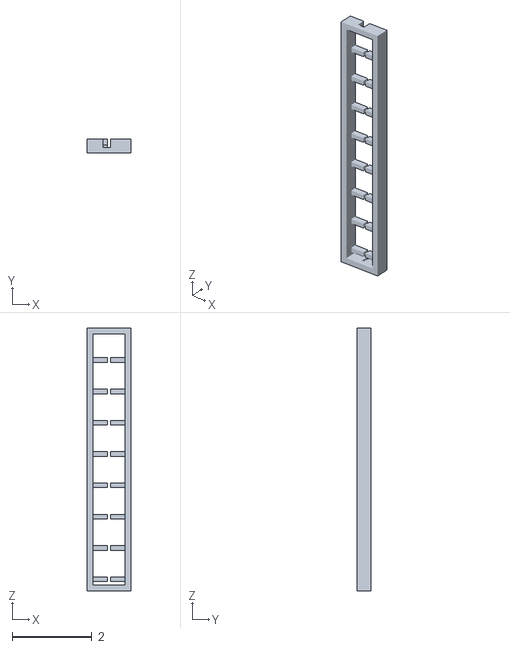
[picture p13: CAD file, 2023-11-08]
Mechanical/3DPrints/MicrophoneSolderingSupport.stl
1.10 x 0.354 x 6.61

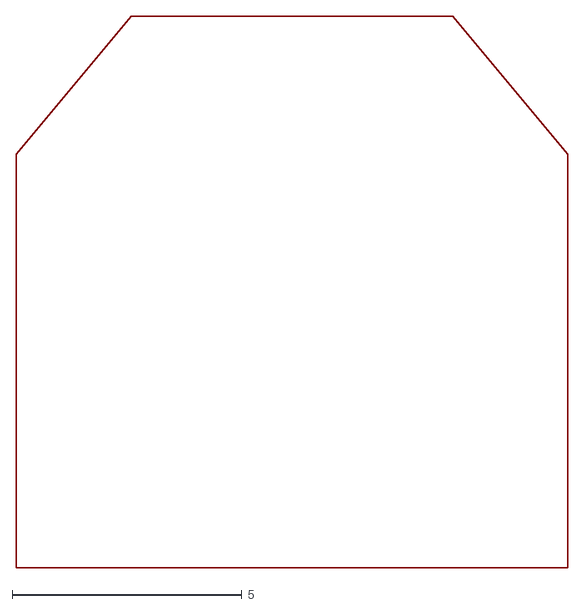
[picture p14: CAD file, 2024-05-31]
Mechanical/LaserCuts/FlySongRGBMirrors.dxf
12.0 x 12.0

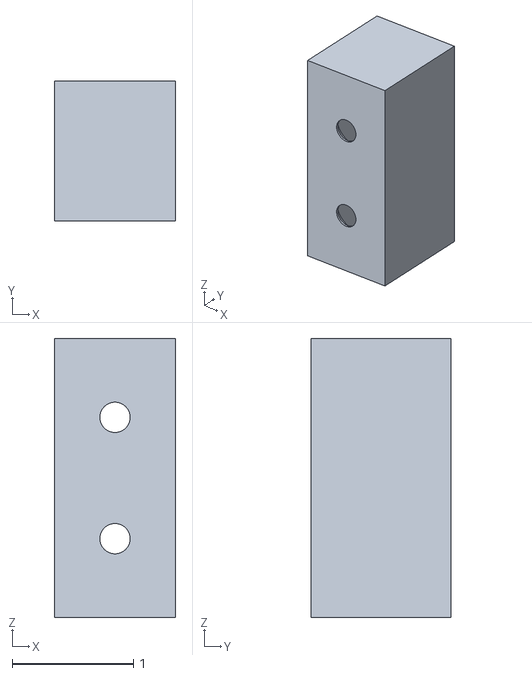
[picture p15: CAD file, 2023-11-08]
Mechanical/3DPrints/BatteryBox_J007969-BLK.stl
1.00 x 1.15 x 2.30

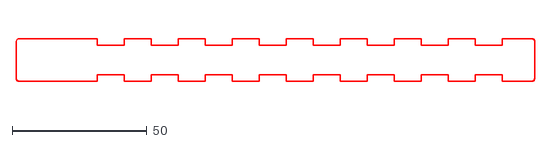
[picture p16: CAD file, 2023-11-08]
Mechanical/LaserCuts/RunCover_J007976_REVB.dxf
192.0 x 15.8

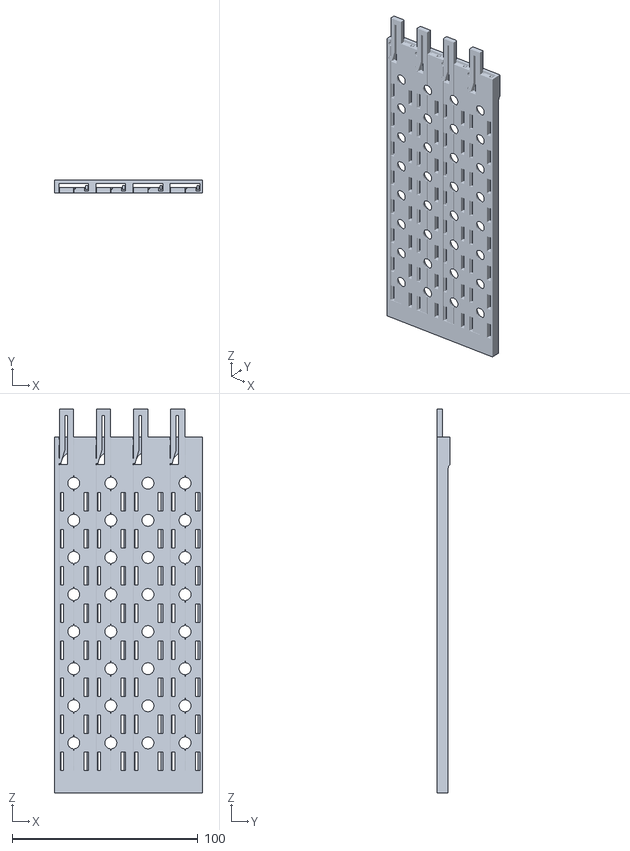
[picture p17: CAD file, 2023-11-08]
Mechanical/3DPrints/WHT_32Chamber_J009584D.stl
80.0 x 7.10 x 207.0

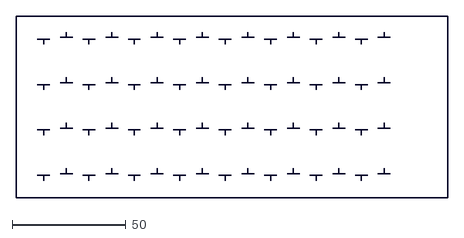
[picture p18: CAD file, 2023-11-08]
Mechanical/LaserCuts/laserMesh.dxf
190.0 x 80.0

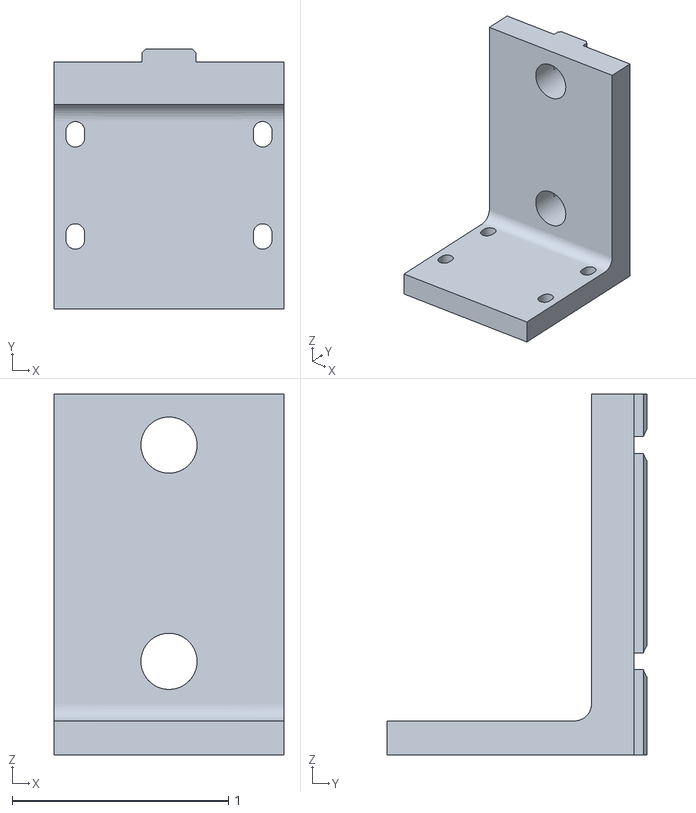
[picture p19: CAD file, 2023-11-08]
Mechanical/3DPrints/CameraMountA_J010538.stl
1.06 x 1.20 x 1.67

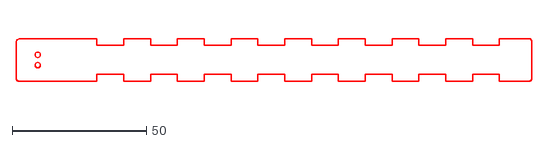
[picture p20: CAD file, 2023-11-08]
Mechanical/LaserCuts/LoadCover_J007976_REVB.dxf
192.0 x 15.8

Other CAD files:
Mechanical/Machined/MicrophoneSolderingHeatSink.dwg
Mechanical/LaserCuts/ChamberSupports_LaserCuts_J008340A.dxf
35mmArena/Mechanical/THERMOFORM MOLD - BUBBLE.ipt
35mmArena/Mechanical/WHT-35mm lid support.ipt
35mmArena/Mechanical/bubbleMold35mm.ipt
35mmArena/Mechanical/plateMold35mm.ipt
Mechanical/3DPrints/BLKbackplaneBracketMid.ipt
Mechanical/3DPrints/BatteryHolder_J007969.ipt
Mechanical/3DPrints/CameraMountA_J010538.ipt
Mechanical/3DPrints/T-Slotted Mirror Support.ipt
miniFlySong/MCAD/WHT_8Chamber_J009584D.ipt

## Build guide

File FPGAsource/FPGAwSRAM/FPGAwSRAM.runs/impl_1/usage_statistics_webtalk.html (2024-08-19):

### Device Usage Page (usage_statistics_webtalk.html)

This HTML page displays the device usage statistics that will be sent to Xilinx.
To see the actual file transmitted to Xilinx, please click here.

software_version_and_target_device
beta | FALSE | build_version | 2552052
date_generated | Mon Aug 19 11:25:25 2024 | os_platform | WIN64
product_version | Vivado v2019.1 (64-bit) | project_id | cac012e5047a4cbc9f132ffdecdeaa17
project_iteration | 684 | random_id | 4edb513f82c851dd963a37df7da409df
registration_id | 4edb513f82c851dd963a37df7da409df | route_design | TRUE
target_device | xc7a15t | target_family | artix7
target_package | ftg256 | target_speed | -1
tool_flow | Vivado

user_environment
cpu_name | 13th Gen Intel(R) Core(TM) i7-13800H | cpu_speed | 2918 MHz
os_name | Windows Server 2016 or Windows 10 | os_release | major release (build 9200)
system_ram | 33.000 GB | total_processors | 1

vivado_usage

gui_handlers
abstractsearchablepanel_show_search=1 | basedialog_cancel=175 | basedialog_ok=112 | basedialog_yes=1
confirmsavetexteditsdialog_cancel=1 | confirmsavetexteditsdialog_yes=5 | filesetpanel_file_set_panel_tree=196 | findandreplacealldialog_close=2
findandreplacealldialog_find=28 | findinfilesview_replace_all_occurrences_in_all_files=7 | findinfilesview_root=757 | flownavigatortreepanel_flow_navigator_tree=4
hcodeeditor_blank_operations=5 | hcodeeditor_commands_to_fold_text=1 | hcodeeditor_diff_with=4 | hcodeeditor_search_text_combo_box=5
hexceptiondialog_exit=1 | hinputhandler_duplicate_selection=1 | hinputhandler_find_text_in_current_file=25 | hinputhandler_indent_selection=9
hinputhandler_replace_text=1 | hinputhandler_toggle_block_comments=2 | hinputhandler_toggle_line_comments=19 | launchpanel_dont_show_this_dialog_again=1
logpanel_log_navigator=1 | mainmenumgr_checkpoint=21 | mainmenumgr_constraints=2 | mainmenumgr_design_hubs=1
mainmenumgr_edit=60 | mainmenumgr_export=19 | mainmenumgr_file=34 | mainmenumgr_help=2
mainmenumgr_import=2 | mainmenumgr_ip=20 | mainmenumgr_open_recent_project=1 | mainmenumgr_project=17
mainmenumgr_reports=2 | mainmenumgr_text_editor=20 | mainmenumgr_view=8 | mainmenumgr_window=4
maintoolbarmgr_run=1 | mainwinmenumgr_layout=2 | messagewithoptiondialog_dont_show_this_dialog_again=1 | msgtreepanel_message_view_tree=292
msgview_critical_warnings=6 | msgview_error_messages=2 | msgview_filter_messages=1 | msgview_information_messages=6
msgview_warning_messages=7 | openfileaction_ok=1 | pacodeeditor_find_in_files=1 | pacodeeditor_find_usages=84
pacommandnames_add_sources=1 | pacommandnames_auto_connect_target=1 | pacommandnames_auto_update_hier=5 | pacommandnames_find_in_files=20
pacommandnames_open_hardware_manager=1 | pacommandnames_open_project=1 | pacommandnames_print=2 | pacommandnames_replace_in_files=7
pacommandnames_run_bitgen=221 | pacommandnames_save_project_as=1 | pacommandnames_src_replace_file=2 | paviews_code=4
paviews_device=1 | paviews_project_summary=1 | programdebugtab_open_target=1 | programdebugtab_program_device=2
progressdialog_cancel=5 | projectnamechooser_choose_project_location=2 | projectnamechooser_project_name=1 | projecttab_reload=1
rdicommands_copy=160 | rdicommands_cut=38 | rdicommands_delete=1 | rdicommands_paste=306
rdicommands_properties=5 | rdicommands_save_all_files=1 | rdicommands_save_file=241 | rdicommands_settings=2
reportipstatusinfodialog_ignore=1 | rtloptionspanel_select_top_module_of_your_design=1 | rungadget_show_error=1 | saveprojectutils_save=7
srcchooserpanel_add_hdl_and_netlist_files_to_your_project=1 | srcmenu_ip_documentation=3 | srcmenu_ip_hierarchy=6 | syntheticagettingstartedview_recent_projects=2
syntheticastatemonitor_cancel=2 | taskbanner_close=1 | touchpointsurveydialog_no=1

java_command_handlers
addsources=7 | autoconnecttarget=1 | closeproject=2 | coreview=7
createblockdesign=1 | customizecore=3 | editdelete=17 | editproperties=5
fileprintcmdhandler=9 | launchprogramfpga=2 | newfile=3 | openfile=1
openhardwaremanager=1 | openproject=1 | projectsummary=1 | recustomizecore=29
reportipstatus=2 | reportutilization=1 | resetlayout=2 | runbitgen=763
runimplementation=3 | runsynthesis=4 | saveallfiles=139 | savefileproxyhandler=419
saveprojectas=3 | setsourceenabled=1 | showproductguide=1 | showview=57
tclfind=4 | toggleviewnavigator=1 | toolsoptions=7 | toolssettings=7
ui.views.b.h.e=7 | ui.views.b.h.f=11 | ui.views.c.h.e=7 | ui.views.c.h.f=21
updatesourcefiles=2 | upgradeip=1 | viewtaskimplementation=21

other_data

guimode=149

project_data
constraintsetcount=1 | core_container=true | currentimplrun=impl_1 | currentsynthesisrun=synth_1
default_library=xil_defaultlib | designmode=RTL | export_simulation_activehdl=12 | export_simulation_ies=12
export_simulation_modelsim=12 | export_simulation_questa=12 | export_simulation_riviera=12 | export_simulation_vcs=12
export_simulation_xsim=12 | implstrategy=Vivado Implementation Defaults | launch_simulation_activehdl=0 | launch_simulation_ies=0
launch_simulation_modelsim=0 | launch_simulation_questa=0 | launch_simulation_riviera=0 | launch_simulation_vcs=0
launch_simulation_xsim=0 | simulator_language=Mixed | srcsetcount=18 | synthesisstrategy=Vivado Synthesis Defaults
target_language=Verilog | target_simulator=XSim | totalimplruns=2 | totalsynthesisruns=2

unisim_transformation

post_unisim_transformation
bufg=2 | carry4=175 | dna_port=1 | dsp48e1=13
fdce=129 | fdpe=44 | fdre=15942 | fdse=24
gnd=137 | ibuf=57 | lut1=159 | lut2=305
lut3=411 | lut4=570 | lut5=413 | lut6=4589
mmcme2_adv=1 | muxf7=1626 | muxf8=801 | obuf=61
obuft=33 | ramb18e1=4 | ramd32=24 | ramd64e=88
rams32=8 | rams64e=16 | srl16e=141 | srlc32e=1

vcc=118

pre_unisim_transformation
bufg=2 | carry4=175 | dna_port=1 | dsp48e1=13
fdce=129 | fdpe=44 | fdre=15942 | fdse=24
gnd=137 | ibuf=24 | iobuf=33 | lut1=159
lut2=305 | lut3=411 | lut4=570 | lut5=363
lut6=4539 | lut6_2=50 | mmcme2_adv=1 | muxf7=1618
muxf8=801 | obuf=61 | ram128x1s=8 | ram32m=4
ram64m=20 | ram64x1d=4 | ramb18e1=4 | srl16e=141
srlc32e=1 | vcc=118

power_opt_design

command_line_options_spo
-cell_types=default::all | -clocks=default::[not_specified] | -exclude_cells=default::[not_specified] | -include_cells=default::[not_specified]

usage
bram_ports_augmented=2 | bram_ports_newly_gated=0 | bram_ports_total=6 | flow_state=default
slice_registers_augmented=0 | slice_registers_newly_gated=0 | slice_registers_total=14841 | srls_augmented=0
srls_newly_gated=0 | srls_total=4

ip_statistics

div_gen_v5_1_11/1
algorithm_type=3 | c_has_aclken=0 | c_has_aresetn=0 | c_has_div_by_zero=0
c_has_s_axis_dividend_tlast=0 | c_has_s_axis_dividend_tuser=0 | c_has_s_axis_divisor_tlast=0 | c_has_s_axis_divisor_tuser=0
c_latency=31 | c_m_axis_dout_tdata_width=48 | c_m_axis_dout_tuser_width=1 | c_s_axis_dividend_tdata_width=32
c_s_axis_dividend_tuser_width=1 | c_s_axis_divisor_tdata_width=16 | c_s_axis_divisor_tuser_width=1 | c_throttle_scheme=4
c_tlast_resolution=0 | c_xdevicefamily=artix7 | core_container=NA | divclk_sel=1
dividend_width=32 | divisor_width=16 | fractional_b=1 | fractional_width=16
iptotal=1 | signed_b=1 | x_ipcorerevision=11 | x_iplanguage=VERILOG
x_iplibrary=ip | x_ipname=div_gen | x_ipproduct=Vivado 2017.1 | x_ipsimlanguage=MIXED
x_ipvendor=xilinx.com | x_ipversion=5.1

report_drc

command_line_options
-append=default::[not_specified] | -checks=default::[not_specified] | -fail_on=default::[not_specified] | -force=default::[not_specified]
-format=default::[not_specified] | -internal=default::[not_specified] | -internal_only=default::[not_specified] | -messages=default::[not_specified]
-name=default::[not_specified] | -no_waivers=default::[not_specified] | -return_string=default::[not_specified] | -ruledecks=default::[not_specified]
-upgrade_cw=default::[not_specified] | -waived=default::[not_specified]

results
cfgbvs-1=1 | check-3=1 | reqp-1840=20

report_methodology

command_line_options
-append=default::[not_specified] | -checks=default::[not_specified] | -fail_on=default::[not_specified] | -force=default::[not_specified]
-format=default::[not_specified] | -messages=default::[not_specified] | -name=default::[not_specified] | -return_string=default::[not_specified]
-slack_lesser_than=default::[not_specified] | -waived=default::[not_specified]

results
lutar-1=4 | timing-17=1 | timing-18=74 | xdch-1=2

xdch-2=18

report_power

command_line_options
-advisory=default::[not_specified] | -append=default::[not_specified] | -file=[specified] | -format=default::text
-hier=default::power | -hierarchical_depth=default::4 | -l=default::[not_specified] | -name=default::[not_specified]
-no_propagation=default::[not_specified] | -return_string=default::[not_specified] | -rpx=[specified] | -verbose=default::[not_specified]
-vid=default::[not_specified] | -xpe=default::[not_specified]

usage
airflow=250 (LFM) | ambient_temp=25.0 (C) | bi-dir_toggle=12.500000 | bidir_output_enable=1.000000
board_layers=12to15 (12 to 15 Layers) | board_selection=medium (10"x10") | bram=0.000491 | clocks=0.011939
confidence_level_clock_activity=High | confidence_level_design_state=High | confidence_level_device_models=High | confidence_level_internal_activity=Medium
confidence_level_io_activity=Low | confidence_level_overall=Low | customer=TBD | customer_class=TBD
devstatic=0.072102 | die=xc7a15tftg256-1 | dsp_output_toggle=12.500000 | dynamic=0.145615
effective_thetaja=4.9 | enable_probability=0.990000 | family=artix7 | ff_toggle=12.500000
flow_state=routed | heatsink=medium (Medium Profile) | i/o=0.016140 | input_toggle=12.500000
junction_temp=26.1 (C) | logic=0.006751 | mgtavcc_dynamic_current=0.000000 | mgtavcc_static_current=0.000000
mgtavcc_total_current=0.000000 | mgtavcc_voltage=1.000000 | mgtavtt_dynamic_current=0.000000 | mgtavtt_static_current=0.000000
mgtavtt_total_current=0.000000 | mgtavtt_voltage=1.200000 | mmcm=0.103040 | netlist_net_matched=NA
off-chip_power=0.000000 | on-chip_power=0.217717 | output_enable=1.000000 | output_load=5.000000
output_toggle=12.500000 | package=ftg256 | pct_clock_constrained=2.000000 | pct_inputs_defined=1
platform=nt64 | process=typical | ram_enable=50.000000 | ram_write=50.000000
read_saif=False | set/reset_probability=0.000000 | signal_rate=False | signals=0.007254
simulation_file=None | speedgrade=-1 | static_prob=False | temp_grade=commercial
thetajb=8.2 (C/W) | thetasa=4.6 (C/W) | toggle_rate=False | user_board_temp=25.0 (C)
user_effective_thetaja=4.9 | user_junc_temp=26.1 (C) | user_thetajb=8.2 (C/W) | user_thetasa=4.6 (C/W)
vccadc_dynamic_current=0.000000 | vccadc_static_current=0.020000 | vccadc_total_current=0.020000 | vccadc_voltage=1.800000
vccaux_dynamic_current=0.057706 | vccaux_io_dynamic_current=0.000000 | vccaux_io_static_current=0.000000 | vccaux_io_total_current=0.000000
vccaux_io_voltage=1.800000 | vccaux_static_current=0.012634 | vccaux_total_current=0.070339 | vccaux_voltage=1.800000
vccbram_dynamic_current=0.000031 | vccbram_static_current=0.000201 | vccbram_total_current=0.000232 | vccbram_voltage=1.000000
vccint_dynamic_current=0.027102 | vccint_static_current=0.009861 | vccint_total_current=0.036963 | vccint_voltage=1.000000
vcco12_dynamic_current=0.000000 | vcco12_static_current=0.000000 | vcco12_total_current=0.000000 | vcco12_voltage=1.200000
vcco135_dynamic_current=0.000000 | vcco135_static_current=0.000000 | vcco135_total_current=0.000000 | vcco135_voltage=1.350000
vcco15_dynamic_current=0.000000 | vcco15_static_current=0.000000 | vcco15_total_current=0.000000 | vcco15_voltage=1.500000
vcco18_dynamic_current=0.000000 | vcco18_static_current=0.000000 | vcco18_total_current=0.000000 | vcco18_voltage=1.800000
vcco25_dynamic_current=0.000000 | vcco25_static_current=0.000000 | vcco25_total_current=0.000000 | vcco25_voltage=2.500000
vcco33_dynamic_current=0.004428 | vcco33_static_current=0.001000 | vcco33_total_current=0.005428 | vcco33_voltage=3.300000

version=2019.1

report_utilization

clocking
bufgctrl_available=32 | bufgctrl_fixed=0 | bufgctrl_used=2 | bufgctrl_util_percentage=6.25
bufhce_available=72 | bufhce_fixed=0 | bufhce_used=0 | bufhce_util_percentage=0.00
bufio_available=20 | bufio_fixed=0 | bufio_used=0 | bufio_util_percentage=0.00
bufmrce_available=10 | bufmrce_fixed=0 | bufmrce_used=0 | bufmrce_util_percentage=0.00
bufr_available=20 | bufr_fixed=0 | bufr_used=0 | bufr_util_percentage=0.00
mmcme2_adv_available=5 | mmcme2_adv_fixed=0 | mmcme2_adv_used=1 | mmcme2_adv_util_percentage=20.00
plle2_adv_available=5 | plle2_adv_fixed=0 | plle2_adv_used=0 | plle2_adv_util_percentage=0.00

dsp
dsps_available=45 | dsps_fixed=0 | dsps_used=0 | dsps_util_percentage=0.00

io_standard
blvds_25=0 | diff_hstl_i=0 | diff_hstl_i_18=0 | diff_hstl_ii=0
diff_hstl_ii_18=0 | diff_hsul_12=0 | diff_mobile_ddr=0 | diff_sstl135=0
diff_sstl135_r=0 | diff_sstl15=0 | diff_sstl15_r=0 | diff_sstl18_i=0
diff_sstl18_ii=0 | hstl_i=0 | hstl_i_18=0 | hstl_ii=0
hstl_ii_18=0 | hsul_12=0 | lvcmos12=0 | lvcmos15=0
lvcmos18=0 | lvcmos25=0 | lvcmos33=1 | lvds_25=0
lvttl=0 | mini_lvds_25=0 | mobile_ddr=0 | pci33_3=0
ppds_25=0 | rsds_25=0 | sstl135=0 | sstl135_r=0
sstl15=0 | sstl15_r=0 | sstl18_i=0 | sstl18_ii=0

tmds_33=0

memory
block_ram_tile_available=25 | block_ram_tile_fixed=0 | block_ram_tile_used=1.5 | block_ram_tile_util_percentage=6.00
ramb18_available=50 | ramb18_fixed=0 | ramb18_used=3 | ramb18_util_percentage=6.00
ramb18e1_only_used=3 | ramb36_fifo_available=25 | ramb36_fifo_fixed=0 | ramb36_fifo_used=0

ramb36_fifo_util_percentage=0.00

primitives
bufg_functional_category=Clock | bufg_used=2 | carry4_functional_category=CarryLogic | carry4_used=136
dna_port_functional_category=Others | dna_port_used=1 | fdce_functional_category=Flop & Latch | fdce_used=132
fdpe_functional_category=Flop & Latch | fdpe_used=44 | fdre_functional_category=Flop & Latch | fdre_used=14644
fdse_functional_category=Flop & Latch | fdse_used=24 | ibuf_functional_category=IO | ibuf_used=57
lut1_functional_category=LUT | lut1_used=93 | lut2_functional_category=LUT | lut2_used=261
lut3_functional_category=LUT | lut3_used=274 | lut4_functional_category=LUT | lut4_used=465
lut5_functional_category=LUT | lut5_used=316 | lut6_functional_category=LUT | lut6_used=4382
mmcme2_adv_functional_category=Clock | mmcme2_adv_used=1 | muxf7_functional_category=MuxFx | muxf7_used=1622
muxf8_functional_category=MuxFx | muxf8_used=799 | obuf_functional_category=IO | obuf_used=61
obuft_functional_category=IO | obuft_used=33 | ramb18e1_functional_category=Block Memory | ramb18e1_used=3
ramd32_functional_category=Distributed Memory | ramd32_used=24 | ramd64e_functional_category=Distributed Memory | ramd64e_used=88
rams32_functional_category=Distributed Memory | rams32_used=8 | rams64e_functional_category=Distributed Memory | rams64e_used=16
srl16e_functional_category=Distributed Memory | srl16e_used=3 | srlc32e_functional_category=Distributed Memory | srlc32e_used=1

slice_logic
f7_muxes_available=16300 | f7_muxes_fixed=0 | f7_muxes_used=1622 | f7_muxes_util_percentage=9.95
f8_muxes_available=8150 | f8_muxes_fixed=0 | f8_muxes_used=799 | f8_muxes_util_percentage=9.80
lut_as_distributed_ram_fixed=0 | lut_as_distributed_ram_used=120 | lut_as_logic_available=10400 | lut_as_logic_fixed=0
lut_as_logic_used=5487 | lut_as_logic_util_percentage=52.76 | lut_as_memory_available=9600 | lut_as_memory_fixed=0
lut_as_memory_used=124 | lut_as_memory_util_percentage=1.29 | lut_as_shift_register_fixed=0 | lut_as_shift_register_used=4
register_as_flip_flop_available=20800 | register_as_flip_flop_fixed=0 | register_as_flip_flop_used=14796 | register_as_flip_flop_util_percentage=71.13
register_as_latch_available=20800 | register_as_latch_fixed=0 | register_as_latch_used=0 | register_as_latch_util_percentage=0.00
slice_luts_available=10400 | slice_luts_fixed=0 | slice_luts_used=5611 | slice_luts_util_percentage=53.95
slice_registers_available=20800 | slice_registers_fixed=0 | slice_registers_used=14796 | slice_registers_util_percentage=71.13
lut_as_distributed_ram_fixed=0 | lut_as_distributed_ram_used=120 | lut_as_logic_available=10400 | lut_as_logic_fixed=0
lut_as_logic_used=5487 | lut_as_logic_util_percentage=52.76 | lut_as_memory_available=9600 | lut_as_memory_fixed=0
lut_as_memory_used=124 | lut_as_memory_util_percentage=1.29 | lut_as_shift_register_fixed=0 | lut_as_shift_register_used=4
lut_in_front_of_the_register_is_unused_fixed=4 | lut_in_front_of_the_register_is_unused_used=12088 | lut_in_front_of_the_register_is_used_fixed=12088 | lut_in_front_of_the_register_is_used_used=1771
register_driven_from_outside_the_slice_fixed=1771 | register_driven_from_outside_the_slice_used=13859 | register_driven_from_within_the_slice_fixed=13859 | register_driven_from_within_the_slice_used=937
slice_available=8150 | slice_fixed=0 | slice_registers_available=20800 | slice_registers_fixed=0
slice_registers_used=14796 | slice_registers_util_percentage=71.13 | slice_used=5695 | slice_util_percentage=69.88
slicel_fixed=0 | slicel_used=4035 | slicem_fixed=0 | slicem_used=1660
unique_control_sets_available=8150 | unique_control_sets_fixed=8150 | unique_control_sets_used=433 | unique_control_sets_util_percentage=5.31
using_o5_and_o6_fixed=5.31 | using_o5_and_o6_used=0 | using_o5_output_only_fixed=0 | using_o5_output_only_used=3
using_o6_output_only_fixed=3 | using_o6_output_only_used=1

specific_feature
bscane2_available=4 | bscane2_fixed=0 | bscane2_used=0 | bscane2_util_percentage=0.00
capturee2_available=1 | capturee2_fixed=0 | capturee2_used=0 | capturee2_util_percentage=0.00
dna_port_available=1 | dna_port_fixed=0 | dna_port_used=1 | dna_port_util_percentage=100.00
efuse_usr_available=1 | efuse_usr_fixed=0 | efuse_usr_used=0 | efuse_usr_util_percentage=0.00
frame_ecce2_available=1 | frame_ecce2_fixed=0 | frame_ecce2_used=0 | frame_ecce2_util_percentage=0.00
icape2_available=2 | icape2_fixed=0 | icape2_used=0 | icape2_util_percentage=0.00
pcie_2_1_available=1 | pcie_2_1_fixed=0 | pcie_2_1_used=0 | pcie_2_1_util_percentage=0.00
startupe2_available=1 | startupe2_fixed=0 | startupe2_used=0 | startupe2_util_percentage=0.00
xadc_available=1 | xadc_fixed=0 | xadc_used=0 | xadc_util_percentage=0.00

synthesis

command_line_options
-assert=default::[not_specified] | -bufg=default::12 | -cascade_dsp=default::auto | -constrset=default::[not_specified]
-control_set_opt_threshold=default::auto | -directive=default::default | -fanout_limit=default::10000 | -flatten_hierarchy=default::rebuilt
-fsm_extraction=default::auto | -gated_clock_conversion=default::off | -generic=default::[not_specified] | -include_dirs=default::[not_specified]
-keep_equivalent_registers=default::[not_specified] | -max_bram=default::-1 | -max_bram_cascade_height=default::-1 | -max_dsp=default::-1
-max_uram=default::-1 | -max_uram_cascade_height=default::-1 | -mode=default::default | -name=default::[not_specified]
-no_lc=default::[not_specified] | -no_srlextract=default::[not_specified] | -no_timing_driven=default::[not_specified] | -part=xc7a15tftg256-1
-resource_sharing=default::auto | -retiming=default::[not_specified] | -rtl=default::[not_specified] | -rtl_skip_constraints=default::[not_specified]
-rtl_skip_ip=default::[not_specified] | -seu_protect=default::none | -sfcu=default::[not_specified] | -shreg_min_size=default::3
-top=FlySongSRAM | -verilog_define=default::[not_specified]

usage
elapsed=00:01:21s | hls_ip=0 | memory_gain=823.773MB | memory_peak=1239.703MB

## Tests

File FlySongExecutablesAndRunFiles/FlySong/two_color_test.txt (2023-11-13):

time, 440nm, 640nm
0, 0, 0
5 10, 0
10, 20, 0
15, 20, 20
20, 0, 10
25, 0, 0

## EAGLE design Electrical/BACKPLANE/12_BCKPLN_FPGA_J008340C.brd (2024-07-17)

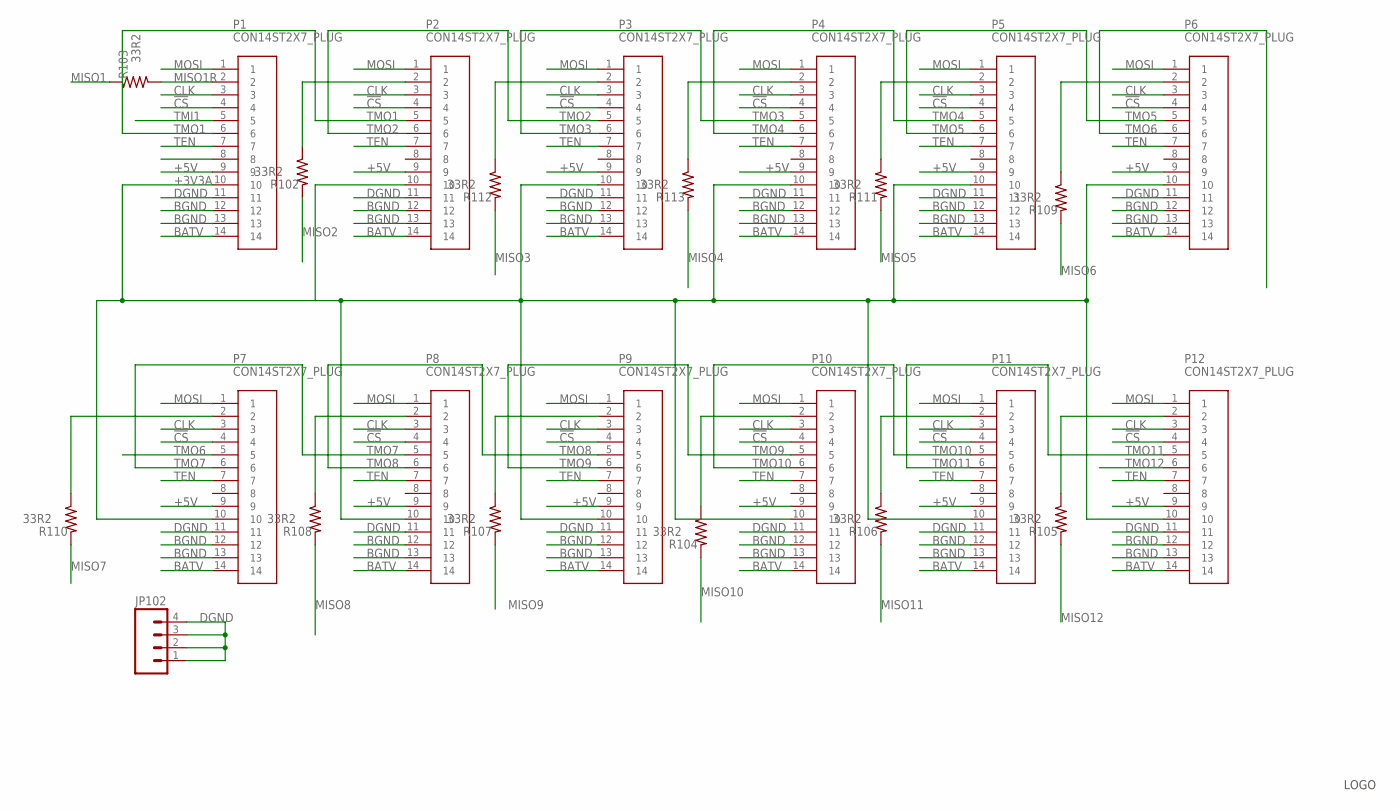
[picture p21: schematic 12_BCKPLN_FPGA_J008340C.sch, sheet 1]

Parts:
JP102: M04LOCK; 1X04_LOCK
P1, P2, P3, P4, P5, P6, P7, P8, P9, P10, P11, P12: CON14ST2X7_PLUG; 2X7_PLUG
R102, R103, R104, R105, R106, R107, R108, R109, R110, R111, R112, R113: 33R2; 0805S
U$1: JFRC-LOGOLOGO_OP; LOGO_BMP_OP

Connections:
!CS: P1.4, P2.4, P3.4, P4.4, P5.4, P6.4, P7.4, P8.4, P9.4, P10.4, P11.4, P12.4; also elsewhere on the board
+3V3A: P1.10, P2.10, P3.10, P4.10, P5.10, P6.10, P7.10, P8.10, P9.10, P10.10, P11.10, P12.10; also elsewhere on the board
+5V: P1.9, P2.9, P3.9, P4.9, P5.9, P6.9, P7.9, P8.9, P9.9, P10.9, P11.9, P12.9; also elsewhere on the board
BATV: P1.14, P2.14, P3.14, P4.14, P5.14, P6.14, P7.14, P8.14, P9.14, P10.14, P11.14, P12.14; also elsewhere on the board
BGND: P1.12, P1.13, P2.12, P2.13, P3.12, P3.13, P4.12, P4.13, P5.12, P5.13, P6.12, P6.13, P7.12, P7.13, P8.12, P8.13, P9.12, P9.13, P10.12, P10.13, P11.12, P11.13, P12.12, P12.13; also elsewhere on the board
CLK: P1.3, P2.3, P3.3, P4.3, P5.3, P6.3, P7.3, P8.3, P9.3, P10.3, P11.3, P12.3; also elsewhere on the board
DGND: JP102.1, JP102.2, JP102.3, JP102.4, P1.11, P2.11, P3.11, P4.11, P5.11, P6.11, P7.11, P8.11, P9.11, P10.11, P11.11, P12.11; also elsewhere on the board
MISO1: R103.2; also elsewhere on the board
MISO1R: P1.2, R103.1
MISO2: R102.2; also elsewhere on the board
MISO3: R112.2; also elsewhere on the board
MISO4: R113.2; also elsewhere on the board
MISO5: R111.2; also elsewhere on the board
MISO6: R109.2; also elsewhere on the board
MISO7: R110.2; also elsewhere on the board
MISO8: R108.2; also elsewhere on the board
MISO9: R107.2; also elsewhere on the board
MISO10: R104.2; also elsewhere on the board
MISO11: R106.2; also elsewhere on the board
MISO12: R105.2; also elsewhere on the board
MOSI: P1.1, P2.1, P3.1, P4.1, P5.1, P6.1, P7.1, P8.1, P9.1, P10.1, P11.1, P12.1; also elsewhere on the board
unnamed: P2.2, R102.1
unnamed: P3.2, R112.1
unnamed: P4.2, R113.1
unnamed: P5.2, R111.1
unnamed: P6.2, R109.1
unnamed: P12.2, R105.1
unnamed: P11.2, R106.1
unnamed: P10.2, R104.1
unnamed: P9.2, R107.1
unnamed: P8.2, R108.1
unnamed: P7.2, R110.1
TEN: P1.7, P2.7, P3.7, P4.7, P5.7, P6.7, P7.7, P8.7, P9.7, P10.7, P11.7, P12.7; also elsewhere on the board
TMI1: P1.5; also elsewhere on the board
TMO1: P1.6, P2.5
TMO2: P2.6, P3.5
TMO3: P3.6, P4.5
TMO4: P4.6, P5.5
TMO5: P5.6, P6.5
TMO6: P6.6, P7.5
TMO7: P7.6, P8.5
TMO8: P8.6, P9.5
TMO9: P9.6, P10.5
TMO10: P10.6, P11.5
TMO11: P11.6, P12.5
TMO12: P12.6; also elsewhere on the board

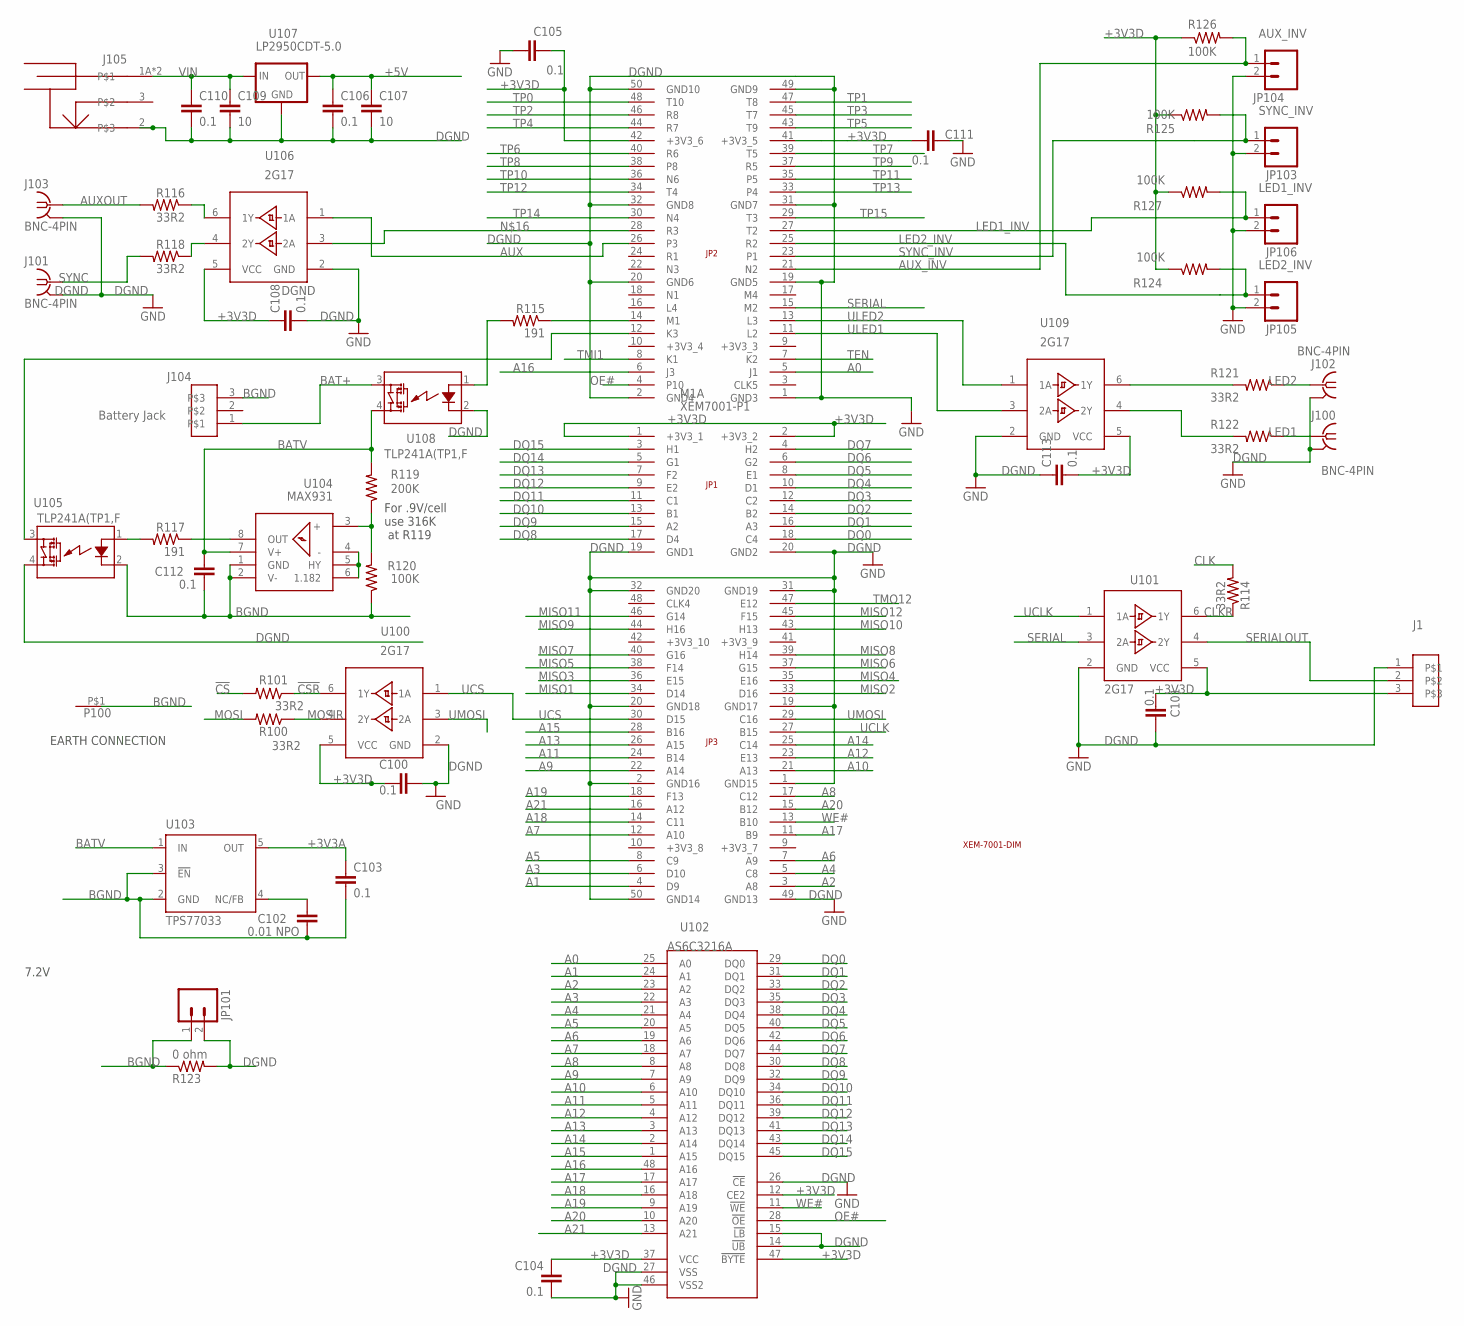
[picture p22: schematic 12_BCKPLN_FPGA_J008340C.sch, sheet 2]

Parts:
C100, C101, C103, C104, C105, C106, C108, C110, C111, C112, C113: 0.1; 0603S
C102: 0.01 NPO; 0805S
C107, C109: 10; 1210S
J1: CON3AMPMODU-3; AMPMODU-3
J100, J101, J102, J103: BNC-4PIN
J104: Battery Jack; 975
J105: POWER_JACK_SHUNTPJ-002; PJ-002
JP101, JP103, JP104, JP105, JP106: M02LOCK; 1X02_LOCK
M1: XEM7001-OUTLINE
M1A: XEM7001-P1; 2X10
M1B: XEM7001-P2; 2X25
M1C: XEM7001-P3; 2X25
P100: CON1BANANA-1; BANANA-1
R100, R101, R114, R116, R118, R121, R122: 33R2; 0805S
R115, R117: 191; 0805S
R119: 200K; 0805S
R120, R124, R125, R126, R127: 100K; 0805S
R123: 0 ohm; 0805S
U100, U101, U106, U109: 2G17; SOT23-6
U102: AS6C3216A; TSSOP48-12X20
U103: TPS77033; SOT23-DBV
U104: MAX931; SOIC8
U105, U108: TLP241A(TP1,F; SMD4-GULL
U107: LP2950CDT-5.0; DPACK

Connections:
!CS: R101.2; also elsewhere on the board
!CSR: R101.1, U100.6 (1Y)
+3V3A: C103.1, U103.5 (OUT); also elsewhere on the board
+3V3D: C100.1, C101.1, C104.1, C105.1, C108.1, C111.1, C113.2, J1.3, M1A.1 (+3V3_1), M1A.2 (+3V3_2), M1B.41 (+3V3_5), M1B.42 (+3V3_6), R124.1, R125.1, R126.1, R127.1, U100.5 (VCC), U101.5 (VCC), U102.12 (CE2), U102.37 (VCC), U102.47 (!BYTE), U106.5 (VCC), U109.5 (VCC)
+5V: C106.1, C107.1, U107.3 (OUT); also elsewhere on the board
A0: M1B.5 (J1), U102.25 (A0)
A1: M1C.4 (D9), U102.24 (A1)
A2: M1C.3 (A8), U102.23 (A2)
A3: M1C.6 (D10), U102.22 (A3)
A4: M1C.5 (C8), U102.21 (A4)
A5: M1C.8 (C9), U102.20 (A5)
A6: M1C.7 (A9), U102.19 (A6)
A7: M1C.12 (A10), U102.18 (A7)
A8: M1C.17 (C12), U102.8 (A8)
A9: M1C.22 (A14), U102.7 (A9)
A10: M1C.21 (A13), U102.6 (A10)
A11: M1C.24 (B14), U102.5 (A11)
A12: M1C.23 (E13), U102.4 (A12)
A13: M1C.26 (A15), U102.3 (A13)
A14: M1C.25 (C14), U102.2 (A14)
A15: M1C.28 (B16), U102.1 (A15)
A16: M1B.6 (J3), U102.48 (A16)
A17: M1C.11 (B9), U102.17 (A17)
A18: M1C.14 (C11), U102.16 (A18)
A19: M1C.18 (F13), U102.9 (A19)
A20: M1C.15 (B12), U102.10 (A20)
A21: M1C.16 (A12), U102.13 (A21)
AUX: M1B.26 (P3), U106.1 (1A)
AUXOUT: J103.S (1), R116.2
AUX_INV: JP104.1, M1B.21 (N2), R126.2
BAT+: J104.1, U108.3 (DS1)
BATV: C112.1, R119.2, U103.1 (IN), U104.7 (V+), U108.4 (DS2); also elsewhere on the board
BGND: C102.2, C103.2, C112.2, J104.3, JP101.1, P100.P$1, R120.1, R123.1, U103.2 (GND), U103.3 (!EN), U104.1 (GND), U104.2 (V-), U105.2 (K); also elsewhere on the board
CLK: R114.2; also elsewhere on the board
CLKR: R114.1, U101.6 (1Y)
DGND: C100.2, C101.2, C104.2, C105.2, C106.2, C107.2, C108.2, C109.2, C110.2, C111.2, C113.1, J1.1, J100.G1 (GND), J100.G2 (GND), J100.G3 (GND), J100.G4 (GND), J101.G1 (GND), J101.G2 (GND), J101.G3 (GND), J101.G4 (GND), J102.G1 (GND), J102.G2 (GND), J102.G3 (GND), J102.G4 (GND), J103.G1 (GND), J103.G2 (GND), J103.G3 (GND), J103.G4 (GND), J105.2, JP101.2, JP103.2, JP104.2, JP105.2, JP106.2, M1A.19 (GND1), M1A.20 (GND2), M1B.1 (GND3), M1B.2 (GND4), M1B.19 (GND5), M1B.20 (GND6), M1B.31 (GND7), M1B.32 (GND8), M1B.49 (GND9), M1B.50 (GND10), M1C.1 (GND15), M1C.2 (GND16), M1C.19 (GND17), M1C.20 (GND18), M1C.31 (GND19), M1C.32 (GND20), M1C.49 (GND13), M1C.50 (GND14), R123.2, U100.2 (GND), U101.2 (GND), U102.14 (!UB), U102.15 (!LB), U102.26 (!CE), U102.27 (VSS), U102.46 (VSS2), U105.4 (DS2), U106.2 (GND), U107.4 (GND), U108.2 (K), U109.2 (GND); also elsewhere on the board
DQ0: M1A.18 (C4), U102.29 (DQ0)
DQ1: M1A.16 (A3), U102.31 (DQ1)
DQ2: M1A.14 (B2), U102.33 (DQ2)
DQ3: M1A.12 (C2), U102.35 (DQ3)
DQ4: M1A.10 (D1), U102.38 (DQ4)
DQ5: M1A.8 (E1), U102.40 (DQ5)
DQ6: M1A.6 (G2), U102.42 (DQ6)
DQ7: M1A.4 (H2), U102.44 (DQ7)
DQ8: M1A.17 (D4), U102.30 (DQ8)
DQ9: M1A.15 (A2), U102.32 (DQ9)
DQ10: M1A.13 (B1), U102.34 (DQ10)
DQ11: M1A.11 (C1), U102.36 (DQ11)
DQ12: M1A.9 (E2), U102.39 (DQ12)
DQ13: M1A.7 (F2), U102.41 (DQ13)
DQ14: M1A.5 (G1), U102.43 (DQ14)
DQ15: M1A.3 (H1), U102.45 (DQ15)
LED1: J100.S (1), R122.1
LED1_INV: JP106.1, M1B.27 (T2), R127.2
LED2: J102.S (1), R121.1
LED2_INV: JP105.1, M1B.25 (R2), R124.2
MISO1: M1C.34 (D14); also elsewhere on the board
MISO2: M1C.33 (D16); also elsewhere on the board
MISO3: M1C.36 (E15); also elsewhere on the board
MISO4: M1C.35 (E16); also elsewhere on the board
MISO5: M1C.38 (F14); also elsewhere on the board
MISO6: M1C.37 (G15); also elsewhere on the board
MISO7: M1C.40 (G16); also elsewhere on the board
MISO8: M1C.39 (H14); also elsewhere on the board
MISO9: M1C.44 (H16); also elsewhere on the board
MISO10: M1C.43 (H13); also elsewhere on the board
MISO11: M1C.46 (G14); also elsewhere on the board
MISO12: M1C.45 (F15); also elsewhere on the board
MOSI: R100.2; also elsewhere on the board
MOSIR: R100.1, U100.4 (2Y)
unnamed: R117.2, U105.1 (A)
unnamed: R121.2, U109.6 (1Y)
unnamed: R115.2, U108.1 (A)
unnamed: M1B.14 (M1), R115.1
unnamed: C102.1, U103.4 (NC/FB)
unnamed: R117.1, U104.8 (OUT)
unnamed: M1B.28 (R3), U106.3 (2A)
unnamed: R119.1, R120.2, U104.3 (+)
unnamed: R116.1, U106.6 (1Y)
unnamed: R118.1, U106.4 (2Y)
unnamed: R122.2, U109.4 (2Y)
OE#: M1B.4 (P10), U102.28 (!OE)
REF: U104.4 (-), U104.5 (HY), U104.6 (1.182)
SERIAL: M1B.15 (M2), U101.3 (2A)
SERIALOUT: J1.2, U101.4 (2Y)
SYNC: J101.S (1), R118.2
SYNC_INV: JP103.1, M1B.23 (P1), R125.2
TEN: M1B.7 (K2); also elsewhere on the board
TMI1: M1B.8 (K1); also elsewhere on the board
TMO12: M1C.47 (E12); also elsewhere on the board
TP0: M1B.48 (T10)
TP1: M1B.47 (T8)
TP2: M1B.46 (R8)
TP3: M1B.45 (T7)
TP4: M1B.44 (R7)
TP5: M1B.43 (T9)
TP6: M1B.40 (R6)
TP7: M1B.39 (T5)
TP8: M1B.38 (P8)
TP9: M1B.37 (R5)
TP10: M1B.36 (N6)
TP11: M1B.35 (P5)
TP12: M1B.34 (T4)
TP13: M1B.33 (P4)
TP14: M1B.30 (N4)
TP15: M1B.29 (T3)
UCLK: M1C.27 (B15), U101.1 (1A)
UCS: M1C.30 (D15), U100.1 (1A)
ULED1: M1B.11 (L2), U109.3 (2A)
ULED2: M1B.13 (L3), U109.1 (1A)
UMOSI: M1C.29 (C16), U100.3 (2A)
VCHECK: M1B.12 (K3), U105.3 (DS1)
VIN: C109.1, C110.1, J105.1A, J105.1B, U107.1 (IN)
WE#: M1C.13 (B10), U102.11 (!WE)

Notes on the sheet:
7.2V
EARTH CONNECTION
For .9V/cell use 316K at R119

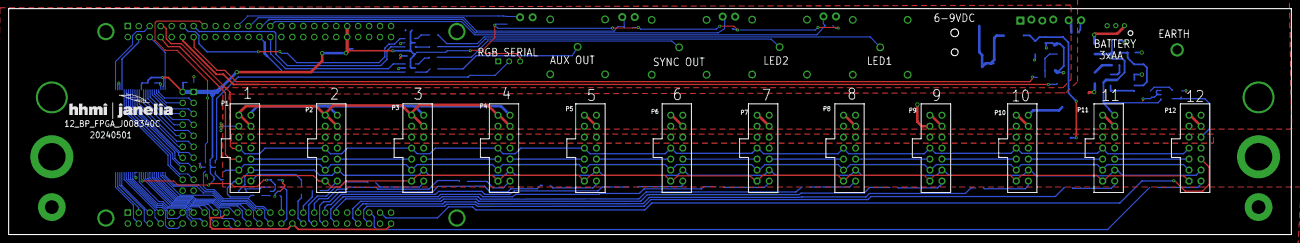
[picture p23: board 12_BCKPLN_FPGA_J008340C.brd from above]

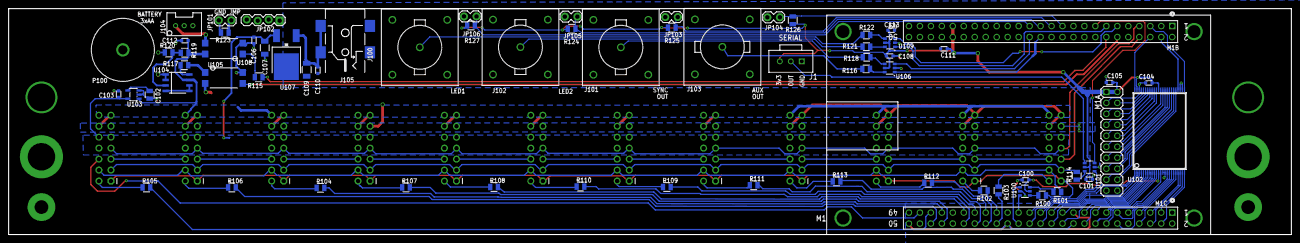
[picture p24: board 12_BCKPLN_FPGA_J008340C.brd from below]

Board: 2 copper layers, 297.0 x 52.3 mm, 83 parts (70 on the bottom side), 121 nets.

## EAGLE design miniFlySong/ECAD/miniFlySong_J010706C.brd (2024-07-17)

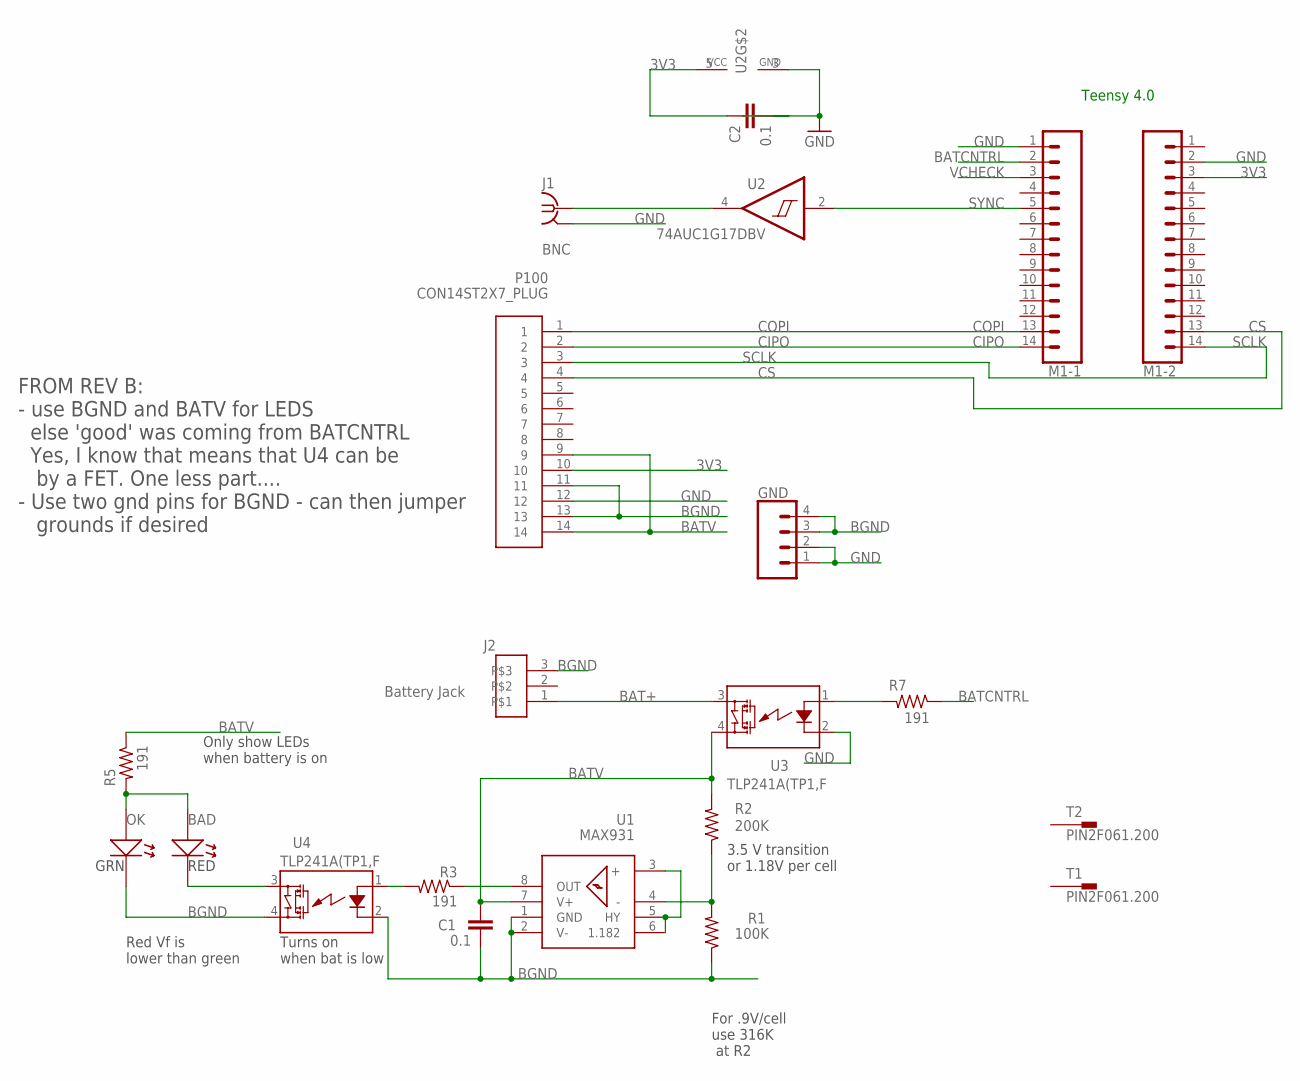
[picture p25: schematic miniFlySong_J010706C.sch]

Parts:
BAD: LED4045; LED_SIDE_SHF4045
C1, C2: 0.1; 0603S
GND: CONN_04LOCK; 1X04_LOCK
J1: BNC; BNC-VERT
J2: Battery Jack; 975
M1-1, M1-2: CONN_14; 1X14
OK: LED4045; LED_SIDE_SHF4045
P100: CON14ST2X7_PLUG; 2X7_PLUG
R1: 100K; 0805S
R2: 200K; 0805S
R3, R5, R7: 191; 0805S
T1, T2: PIN2F061.200; F061.200
U1: MAX931; SOIC8
U2: 74AUC1G17DBV; SOT23-5
U3, U4: TLP241A(TP1,F; SMD4-GULL

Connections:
3V3: C2.1, M1-2.3, P100.10, U2.5 (VCC)
BAT+: J2.1, U3.3 (DS1)
BATCNTRL: M1-1.2, R7.1
BATV: C1.1, P100.9, P100.14, R2.2, R5.1, U1.7 (V+), U3.4 (DS2)
BGND: C1.2, GND.3, GND.4, J2.3, OK.C (K), P100.11, P100.13, R1.1, U1.1 (GND), U1.2 (V-), U4.2 (K), U4.4 (DS2)
CIPO: M1-1.14, P100.2
COPI: M1-1.13, P100.1
CS: M1-2.13, P100.4
GND: C2.2, GND.1, GND.2, J1.2 (GND), M1-1.1, M1-2.2, P100.12, U2.3 (GND), U3.2 (K)
unnamed: J1.1, U2.4 (O)
unnamed: BAD.A, OK.A, R5.2
unnamed: BAD.C (K), U4.3 (DS1)
unnamed: R3.2, U4.1 (A)
unnamed: R7.2, U3.1 (A)
unnamed: R3.1, U1.8 (OUT)
unnamed: R1.2, R2.1, U1.4 (-)
REF: U1.3 (+), U1.5 (HY), U1.6 (1.182)
SCLK: M1-2.14, P100.3
SYNC: M1-1.5, U2.2 (I)
VCHECK: M1-1.3

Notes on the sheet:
For .9V/cell use 316K at R2
RED
GRN
3.5 V transition or 1.18V per cell
Turns on when bat is low
Red Vf is lower than green
Only show LEDs when battery is on
FROM REV B: - use BGND and BATV for LEDS else 'good' was coming from BATCNTRL Yes, I know that means that U4 can be by a FET. One less part.... - Use two gnd pins for BGND - can then jumper grounds if desired
Teensy 4.0

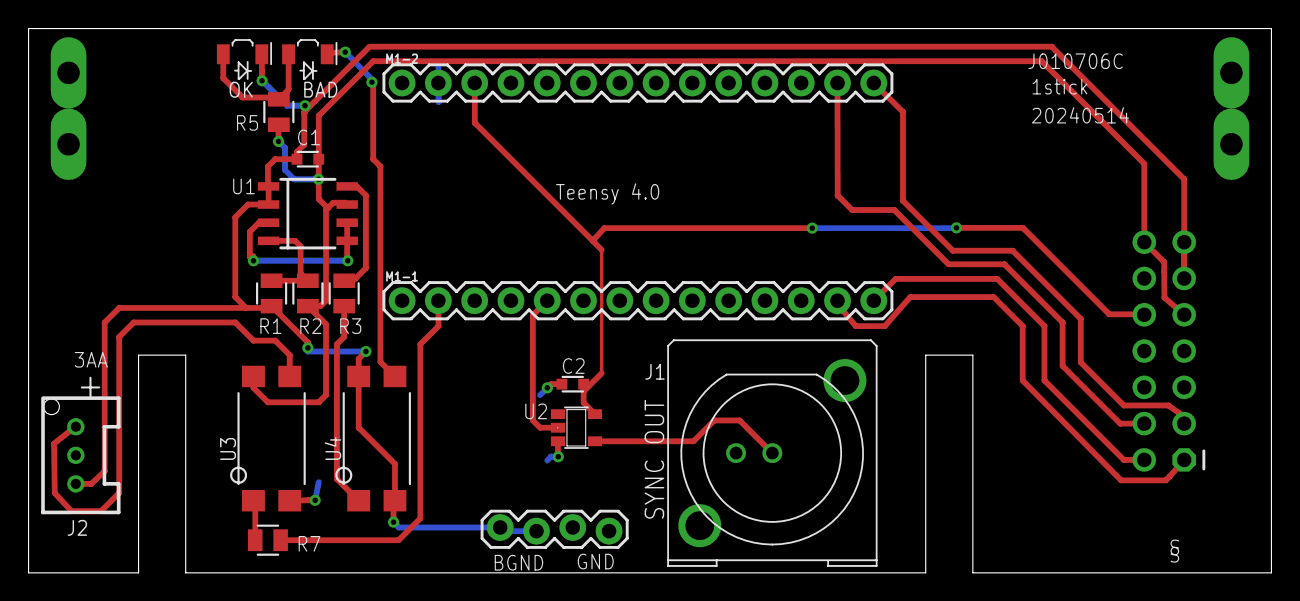
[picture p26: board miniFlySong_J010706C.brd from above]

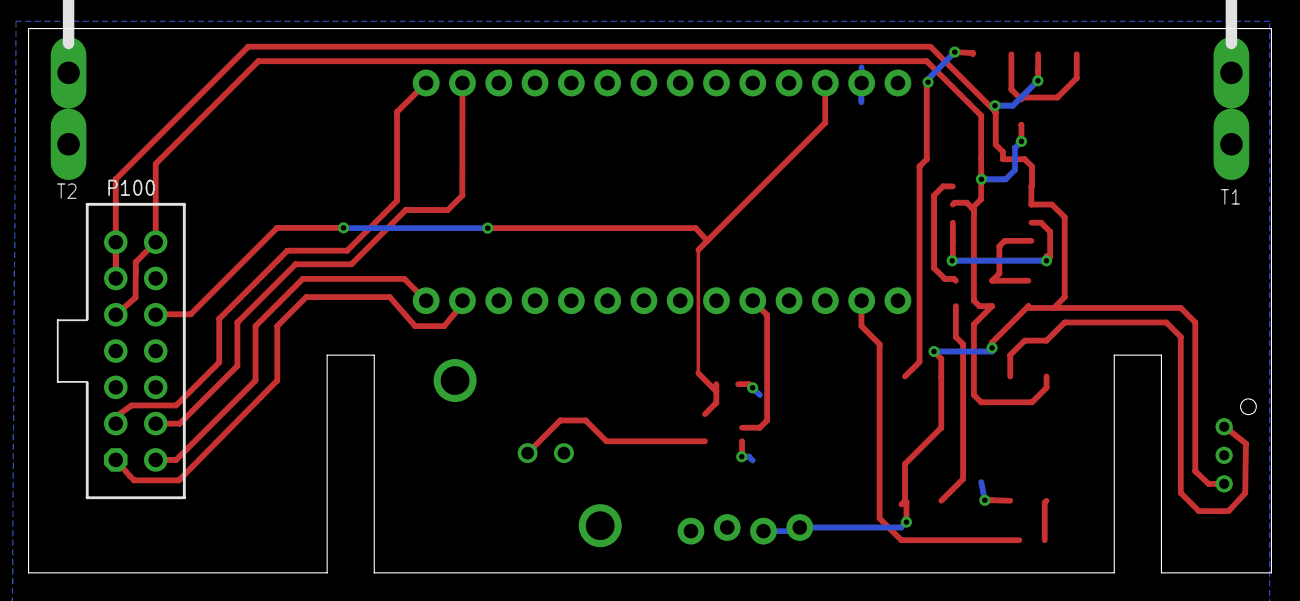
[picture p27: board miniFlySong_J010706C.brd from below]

Board: 2 copper layers, 87.0 x 38.1 mm, 21 parts (3 on the bottom side), 19 nets.

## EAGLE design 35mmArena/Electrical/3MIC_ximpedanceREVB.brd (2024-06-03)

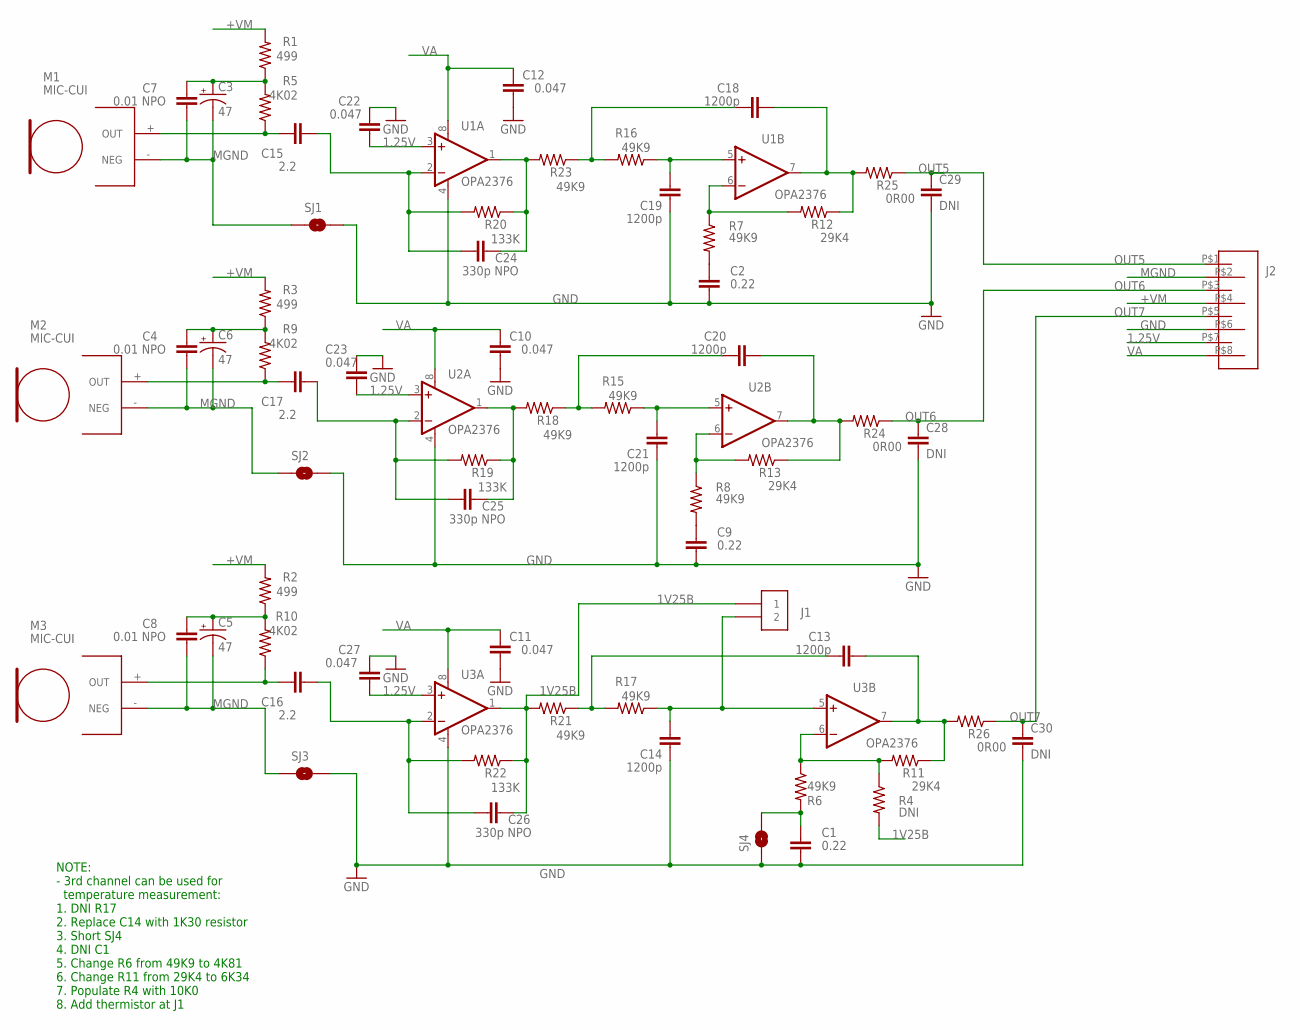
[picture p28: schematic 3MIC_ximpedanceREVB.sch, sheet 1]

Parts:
C1, C2, C9: 0.22; 1206S
C3, C5, C6: 47; EIA3216
C4, C7, C8: 0.01 NPO; 0603S
C10, C11, C12, C22, C23, C27: 0.047; 0805S
C13, C14, C18, C19, C20, C21: 1200p; 1206S
C15, C16, C17: 2.2; 1210S
C24, C25, C26: 330p NPO; 0805S
C28, C29, C30: DNI; 0603S
J1: CON2TIP-BOT-PADS; TOP-BOT-PADS
J2: CON8; CON8-EDGE
M1, M2, M3: MIC-CUI; CUI_EDGE
R1, R2, R3: 499; 0603S
R4: DNI; 0603S
R5, R9, R10: 4K02; 0603S
R6, R7, R8, R15, R16, R17, R18, R21, R23: 49K9; 0603S
R11, R12, R13: 29K4; 0603S
R19, R20, R22: 133K; 0603S
R24, R25, R26: 0R00; 0603S
SJ1, SJ2, SJ3: SOLDERJUMPERTRACE; SJ_2S-TRACE
SJ4: SOLDERJUMPERNO; SJ_2S-NO
U1, U2, U3: OPA2376; MSOP08

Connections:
1.25V: C22.2, C23.2, C27.2, J2.P$7 (7), U1.3 (+IN), U2.3 (+IN), U3.3 (+IN)
1V25B: C26.1, J1.1, R4.2, R21.2, R22.1, U3.1 (OUT)
+VM: J2.P$4 (4), R1.2, R2.2, R3.2
GND: C1.1, C2.1, C9.1, C10.1, C11.1, C12.1, C14.1, C19.1, C21.1, C22.1, C23.1, C27.1, C28.2, C29.2, C30.2, J2.P$6 (6), SJ1.2, SJ2.2, SJ3.2, SJ4.1, U1.4 (V-), U2.4 (V-), U3.4 (V-)
M5: C18.1, R12.1, R25.2, U1.7 (OUT)
M6: C20.1, R13.1, R24.2, U2.7 (OUT)
M7: C13.1, R11.1, R26.2, U3.7 (OUT)
MGND: C3.C (-), C4.2, C5.C (-), C6.C (-), C7.2, C8.2, J2.P$2 (2), M1.- (NEG), M2.- (NEG), M3.- (NEG), SJ1.1, SJ2.1, SJ3.1
unnamed: C4.1, C6.A (+), R3.1, R9.2
unnamed: C5.A (+), C8.1, R2.1, R10.2
unnamed: C3.A (+), C7.1, R1.1, R5.2
unnamed: C15.2, C24.2, R20.2, U1.2 (-IN)
unnamed: C24.1, R20.1, R23.2, U1.1 (OUT)
unnamed: C18.2, R16.2, R23.1
unnamed: C19.2, R16.1, U1.5 (+IN)
unnamed: C2.2, R7.2
unnamed: R7.1, R12.2, U1.6 (-IN)
unnamed: C17.1, M2.+ (OUT), R9.1
unnamed: C17.2, C25.2, R19.2, U2.2 (-IN)
unnamed: C25.1, R18.2, R19.1, U2.1 (OUT)
unnamed: C20.2, R15.2, R18.1
unnamed: C21.2, R15.1, U2.5 (+IN)
unnamed: C9.2, R8.2
unnamed: R8.1, R13.2, U2.6 (-IN)
unnamed: C16.1, M3.+ (OUT), R10.1
unnamed: C16.2, C26.2, R22.2, U3.2 (-IN)
unnamed: C13.2, R17.2, R21.1
unnamed: C14.2, J1.2, R17.1, U3.5 (+IN)
unnamed: C1.2, R6.2, SJ4.2
unnamed: R4.1, R6.1, R11.2, U3.6 (-IN)
unnamed: C15.1, M1.+ (OUT), R5.1
OUT5: C29.1, J2.P$1 (1), R25.1
OUT6: C28.1, J2.P$3 (3), R24.1
OUT7: C30.1, J2.P$5 (5), R26.1
VA: C10.2, C11.2, C12.2, J2.P$8 (8), U1.8 (V+), U2.8 (V+), U3.8 (V+)

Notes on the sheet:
NOTE: - 3rd channel can be used for temperature measurement: 1. DNI R17 2. Replace C14 with 1K30 resistor 3. Short SJ4 4. DNI C1 5. Change R6 from 49K9 to 4K81 6. Change R11 from 29K4 to 6K34 7. Populate R4 with 10K0 8. Add thermistor at J1

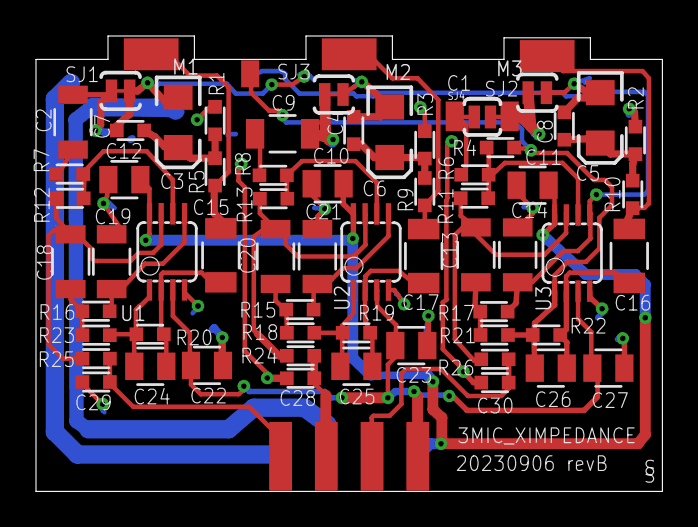
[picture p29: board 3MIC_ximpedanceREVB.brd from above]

Board: 2 copper layers, 34.8 x 25.3 mm, 67 parts (0 on the bottom side), 35 nets.

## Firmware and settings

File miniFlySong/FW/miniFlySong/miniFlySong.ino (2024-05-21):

// miniFlySong

// Teensy 4 interface to a single FlySong 8-Channel Microphone Board. 
// Prints out raw data to USB-Serial as binary values 0x7FFF is reserved as the sync word so 0x7FFF data -> 0x7FFE
// Set NUMCHAN to the number of channels to digitize
// Did not implement temperature readings, but it could be added

// sws jET Janelia HHMI

// Hardware:
// - 3 cell AA or AAA pack connected to microphone power and 5V inputs (for older microphone boards with on
//    on board 3.3 V voltage regulator) 

//#define TESTMODE  // define to send ramp data 
#define NUMCHAN 8  // how many channels to record
#define SAMPLERATE  5000 // samples per second
// #define ASCIIOUT  // enable to put out data in ASCII

#define VERSION "20240320"

// 20240320 sws
// - added battery on/off

// 20240312 sws
// - add clock out (SYNC) and command polling

// 20230410 sws
// - basics working

#include <SPI.h>
#include <Cmd.h>


#define batOnPin 0
#define batCheckPin 1
#define batGoodPin 22
#define batBadPin 23

#define csPin 14
#define triggerPin 3

#define MINSYNC 0.01 // 1
#define MAXSYNC 5000
volatile boolean state = false;
float syncRate = 30;
boolean clockOutEnabled = false;
 
//int16_t data[12];
//int16_t data0, data1, data2, data3, data4, data5, data6, data7, data8, data9, data10, data11;

#define BUFSIZE 0x8000

uint16_t buff[BUFSIZE]; 
uint16_t * bp;
uint16_t readPtr;
uint16_t writePtr;
volatile uint16_t bufLevel = 0;

volatile int32_t sampleCount = 0;

IntervalTimer sampleTimer;
IntervalTimer syncTimer;

uint8_t numCh = NUMCHAN;

// channel order starts with 1 as cmd sets channel for the NEXT ch to digitize

uint16_t ADCcmd[] = {0xb400, 0xe400, 0xa400, 0xd400, 0x9400, 0xc400, 0x8400, 0xf400 };

uint16_t maxLevel;

union 
{
  uint16_t intData[8];
  uint8_t byteData[16];
} ADCdata; 

union
{
   uint16_t uint;
   uint8_t bytes[2];
} dataOut;

void writeToBuf(uint16_t data)
{
  if( bufLevel < BUFSIZE )
  {
     buff[writePtr] = data;
     writePtr++;
     if( writePtr == BUFSIZE ) writePtr = 0;
     bufLevel++;   
     if( bufLevel > maxLevel ) maxLevel = bufLevel;
  }
}

uint16_t readFromBuf(void)
{
uint16_t data;

   noInterrupts();
   data = buff[readPtr];
   readPtr++;
   if( readPtr == BUFSIZE ) readPtr = 0;
   bufLevel--;         
   interrupts();   
   return data;
}

void nextSample()
{  
uint16_t dataIn;
   
  writeToBuf(0x7fff);  // sync word

//  writeToBuf(maxLevel);
   
  for( uint ch = 0; ch < NUMCHAN; ch++)
  { 
      uint16_t cmd = ADCcmd[ch];
      if( ch == (NUMCHAN-1) ) cmd = ADCcmd[7]; // last one always goes back to ch 0
      digitalWriteFast(csPin, HIGH);
//      delayNanoseconds(100);   // this does not seem to work consistantly 
      delayMicroseconds(1);
      digitalWriteFast(csPin, LOW);  
      
      delayMicroseconds(4);  // conversion time

      dataIn = SPI.transfer16(cmd) ^ 0x8000;  // make into signed value

#ifdef TESTMODE
  dataIn = 0xffff & (sampleCount + 256 * ch);
#endif
      
      if( dataIn == 0x7fff) dataIn = 0x7ffe;  // no data can be same as sync word
         
      writeToBuf(dataIn);

//      ADCdata.intData[ch] = SPI.transfer16(cmd) ; //^ 0x8000;
//      if( ADCdata.intData[ch] == 0xffff ) ADCdata.intData[ch] = 0xfffe;
//
//      #ifdef ASCIIOUT
//        Serial.print(ADCdata.intData[ch]);  
//        if( ch < numCh-1)  Serial.print(',');
//      #endif  
 
   }

//   #ifdef ASCIIOUT
//     Serial.println(); 
//   #else  
//      Serial.write(0xff);
//      Serial.write(0xff);
//      Serial.write(ADCdata.byteData, NUMCHAN*2);
//   #endif   
   
   sampleCount++;
}

// ========================
// === S Y N C    I N T ===
// ========================

// camera sync
void syncInt(void)
{
  if ( state )
  {
    digitalWriteFast(triggerPin, HIGH);
    state = false;
  }
  else
  {
    digitalWriteFast(triggerPin, LOW);
    state = true;
  }
}


// ==================================
// === S Y N C   R A T E   C M D  ===
// ==================================
// set the sync output rate for triggering camera

void syncRateCmd(int arg_cnt, char **args)
{
  float tsync;
//Serial.println( args[1]);
  if ( arg_cnt > 1 )
  {
    tsync = cmdStr2Float(args[1]);
    if ( (tsync > MINSYNC) && (tsync < MAXSYNC) )
    {
      syncRate = tsync;
      digitalWriteFast(triggerPin, HIGH);
      state = false;
      if( clockOutEnabled )
      {       
        syncTimer.update( 500000/syncRate);
      }
      else
      {
        syncTimer.begin(syncInt, 500000 / syncRate); // change immediately (or start if ended)
      }
      clockOutEnabled = true;
    }
    else
    {
      if ( (tsync > -0.001) && (tsync < 0.001) ) // if '0' then turn sync off
      {
        clockOutEnabled = false;
        syncTimer.end();
        digitalWriteFast(triggerPin, LOW);
      }
    }
  }
  else
  {
    Stream *s = cmdGetStream();
    s->println(syncRate);
  }
}

// ==================================
// === R U N    E X P E R I M E N T  ===
// ==================================

void runExperiment(int arg_cnt, char **args)
{
  state = false;
  digitalWriteFast(triggerPin, HIGH);
  if( clockOutEnabled )
  {       
    syncTimer.update( 500000/syncRate);
  }
  else
  {
    syncTimer.begin(syncInt, 500000 / syncRate); // change immediately (or start if ended)
  }
  clockOutEnabled = true;
}


// ==================================
// === S T O P   E X P E R I M E N T  ===
// ==================================

void stopExperiment(int arg_cnt, char **args)
{
  digitalWriteFast( triggerPin, LOW);
  syncTimer.end(); // stop clock out
  clockOutEnabled = false;
}

// ==================================
// === B A T  O N  C M D   ===
// ==================================

void batOnCmd(int arg_cnt, char **args)
{
  digitalWriteFast(batOnPin, HIGH);
}

// ==================================
// === B A T  O F F  C M D   ===
// ==================================

void batOffCmd(int arg_cnt, char **args)
{
  digitalWriteFast(batOnPin, LOW);
}


// ==================================
// === H E L P   C M D   ===
// ==================================

void helpCmd(int arg_cnt, char **args)
{
  Serial.println(VERSION);
}

boolean batOn = false;

void setup() 
{

  pinMode(csPin, OUTPUT);
  digitalWriteFast(csPin, LOW);

  pinMode( triggerPin, OUTPUT);
  digitalWriteFast( triggerPin, LOW);

  pinMode( batOnPin, OUTPUT);    // battery off until we connect
  digitalWriteFast( batOnPin, LOW);
 
  Serial.begin(15200);
  while(!Serial); 
  
  digitalWriteFast( batOnPin, HIGH); 
  batOn = true;

  SPI.begin();
  
  SPI.beginTransaction(SPISettings(20000000, MSBFIRST, SPI_MODE0));
  
  bp = buff;
  readPtr = 0;
  writePtr = 0;
  bufLevel = 0;
  sampleCount = 0;
  maxLevel = 0;

  cmdInit(&Serial);
  cmdAdd("SYNC", syncRateCmd);
  cmdAdd("RX", runExperiment);
  cmdAdd("SX", stopExperiment);
  cmdAdd("ON", batOnCmd);
  cmdAdd("OFF", batOffCmd);
//  cmdAdd("BAT", batCheckCmd);
  cmdAdd("???", helpCmd);
  
  delay(1000);
  
 // sampleTimer.begin( nextSample, 1e6/SAMPLERATE); 
}


void loop() 
{

   cmdPoll();  // watch for sync commands

   if( Serial )
   {
      if( batOn == false)  // if connected and battery off , turn on
      {
         digitalWriteFast(batOnPin, HIGH);
         batOn == true;
      }   
   }
   else
   {
      if( batOn == true )
      {
        digitalWriteFast(batOnPin, LOW);
        batOn = false;
      }
   }

   if( bufLevel > 0 ) 
   {
     dataOut.uint = readFromBuf();
     Serial.write(dataOut.bytes, 2);   
   }
  // comment all this out for continuous running
  // following is for testing - send 1 million samples, stop, wait 5 secs, go again
  
//  if( sampleCount >= 1e6 ) 
//  {
//    Serial.write( (uint8_t) maxLevel >> 8);
//    Serial.write( (uint8_t) maxLevel & 0xff);
//    sampleTimer.end();     
//    delay(10000);
//    sampleTimer.begin( nextSample, 1e6/SAMPLERATE); 
//    readPtr = 0;
//    writePtr = 0;
//    bufLevel = 0;
//    maxLevel = 0;
//    sampleCount = 0;
//  }
  

  
}

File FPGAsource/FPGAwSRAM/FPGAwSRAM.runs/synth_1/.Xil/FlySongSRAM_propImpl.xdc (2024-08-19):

set_property SRC_FILE_INFO {cfile:C:/Users/sawtelles/Documents/GitHub/FlySong/FPGAsource/FPGAwSRAM/FPGAwSRAM.srcs/constrs_1/imports/96mic/xem7001.xdc rfile:../../../FPGAwSRAM.srcs/constrs_1/imports/96mic/xem7001.xdc id:1} [current_design]
set_property src_info {type:XDC file:1 line:12 export:INPUT save:INPUT read:READ} [current_design]
set_property PACKAGE_PIN K12 [get_ports {hi_muxsel}]
set_property src_info {type:XDC file:1 line:18 export:INPUT save:INPUT read:READ} [current_design]
set_property PACKAGE_PIN N11 [get_ports {hi_in[0]}]
set_property src_info {type:XDC file:1 line:19 export:INPUT save:INPUT read:READ} [current_design]
set_property PACKAGE_PIN R13 [get_ports {hi_in[1]}]
set_property src_info {type:XDC file:1 line:20 export:INPUT save:INPUT read:READ} [current_design]
set_property PACKAGE_PIN R12 [get_ports {hi_in[2]}]
set_property src_info {type:XDC file:1 line:21 export:INPUT save:INPUT read:READ} [current_design]
set_property PACKAGE_PIN P13 [get_ports {hi_in[3]}]
set_property src_info {type:XDC file:1 line:22 export:INPUT save:INPUT read:READ} [current_design]
set_property PACKAGE_PIN T13 [get_ports {hi_in[4]}]
set_property src_info {type:XDC file:1 line:23 export:INPUT save:INPUT read:READ} [current_design]
set_property PACKAGE_PIN T12 [get_ports {hi_in[5]}]
set_property src_info {type:XDC file:1 line:24 export:INPUT save:INPUT read:READ} [current_design]
set_property PACKAGE_PIN P11 [get_ports {hi_in[6]}]
set_property src_info {type:XDC file:1 line:25 export:INPUT save:INPUT read:READ} [current_design]
set_property PACKAGE_PIN R10 [get_ports {hi_in[7]}]
set_property src_info {type:XDC file:1 line:30 export:INPUT save:INPUT read:READ} [current_design]
set_property PACKAGE_PIN R15 [get_ports {hi_out[0]}]
set_property src_info {type:XDC file:1 line:31 export:INPUT save:INPUT read:READ} [current_design]
set_property PACKAGE_PIN N13 [get_ports {hi_out[1]}]
set_property src_info {type:XDC file:1 line:34 export:INPUT save:INPUT read:READ} [current_design]
set_property PACKAGE_PIN T15 [get_ports {hi_inout[0]}]
set_property src_info {type:XDC file:1 line:35 export:INPUT save:INPUT read:READ} [current_design]
set_property PACKAGE_PIN T14 [get_ports {hi_inout[1]}]
set_property src_info {type:XDC file:1 line:36 export:INPUT save:INPUT read:READ} [current_design]
set_property PACKAGE_PIN R16 [get_ports {hi_inout[2]}]
set_property src_info {type:XDC file:1 line:37 export:INPUT save:INPUT read:READ} [current_design]
set_property PACKAGE_PIN P16 [get_ports {hi_inout[3]}]
set_property src_info {type:XDC file:1 line:38 export:INPUT save:INPUT read:READ} [current_design]
set_property PACKAGE_PIN P15 [get_ports {hi_inout[4]}]
set_property src_info {type:XDC file:1 line:39 export:INPUT save:INPUT read:READ} [current_design]
set_property PACKAGE_PIN N16 [get_ports {hi_inout[5]}]
set_property src_info {type:XDC file:1 line:40 export:INPUT save:INPUT read:READ} [current_design]
set_property PACKAGE_PIN M16 [get_ports {hi_inout[6]}]
set_property src_info {type:XDC file:1 line:41 export:INPUT save:INPUT read:READ} [current_design]
set_property PACKAGE_PIN M12 [get_ports {hi_inout[7]}]
set_property src_info {type:XDC file:1 line:42 export:INPUT save:INPUT read:READ} [current_design]
set_property PACKAGE_PIN L13 [get_ports {hi_inout[8]}]
set_property src_info {type:XDC file:1 line:43 export:INPUT save:INPUT read:READ} [current_design]
set_property PACKAGE_PIN K13 [get_ports {hi_inout[9]}]
set_property src_info {type:XDC file:1 line:44 export:INPUT save:INPUT read:READ} [current_design]
set_property PACKAGE_PIN M14 [get_ports {hi_inout[10]}]
set_property src_info {type:XDC file:1 line:45 export:INPUT save:INPUT read:READ} [current_design]
set_property PACKAGE_PIN L14 [get_ports {hi_inout[11]}]
set_property src_info {type:XDC file:1 line:46 export:INPUT save:INPUT read:READ} [current_design]
set_property PACKAGE_PIN K16 [get_ports {hi_inout[12]}]
set_property src_info {type:XDC file:1 line:47 export:INPUT save:INPUT read:READ} [current_design]
set_property PACKAGE_PIN K15 [get_ports {hi_inout[13]}]
set_property src_info {type:XDC file:1 line:48 export:INPUT save:INPUT read:READ} [current_design]
set_property PACKAGE_PIN J14 [get_ports {hi_inout[14]}]
set_property src_info {type:XDC file:1 line:49 export:INPUT save:INPUT read:READ} [current_design]
set_property PACKAGE_PIN J13 [get_ports {hi_inout[15]}]
set_property src_info {type:XDC file:1 line:52 export:INPUT save:INPUT read:READ} [current_design]
set_property PACKAGE_PIN M15 [get_ports {hi_aa}]
set_property src_info {type:XDC file:1 line:71 export:INPUT save:INPUT read:READ} [current_design]
set_property PACKAGE_PIN H5 [get_ports {led[0]}]
set_property src_info {type:XDC file:1 line:72 export:INPUT save:INPUT read:READ} [current_design]
set_property PACKAGE_PIN F3 [get_ports {led[1]}]
set_property src_info {type:XDC file:1 line:73 export:INPUT save:INPUT read:READ} [current_design]
set_property PACKAGE_PIN E3 [get_ports {led[2]}]
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

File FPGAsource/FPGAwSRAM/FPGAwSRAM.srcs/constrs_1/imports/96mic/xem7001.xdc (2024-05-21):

############################################################################
# XEM7001 - Xilinx constraints file
#
# Pin mappings for the XEM7001.  Use this as a template and comment out 
# the pins that are not used in your design.  (By default, map will fail
# if this file contains constraints for signals not in your design).
#
# Copyright (c) 2004-2015 Opal Kelly Incorporated
############################################################################
set_property BITSTREAM.GENERAL.COMPRESS True [current_design]

set_property PACKAGE_PIN K12 [get_ports {hi_muxsel}]
set_property IOSTANDARD LVCMOS33 [get_ports {hi_muxsel}]

############################################################################
## FrontPanel Host Interface
############################################################################
set_property PACKAGE_PIN N11 [get_ports {hi_in[0]}]
set_property PACKAGE_PIN R13 [get_ports {hi_in[1]}]
set_property PACKAGE_PIN R12 [get_ports {hi_in[2]}]
set_property PACKAGE_PIN P13 [get_ports {hi_in[3]}]
set_property PACKAGE_PIN T13 [get_ports {hi_in[4]}]
set_property PACKAGE_PIN T12 [get_ports {hi_in[5]}]
set_property PACKAGE_PIN P11 [get_ports {hi_in[6]}]
set_property PACKAGE_PIN R10 [get_ports {hi_in[7]}]

set_property SLEW FAST [get_ports {hi_in[*]}]
set_property IOSTANDARD LVCMOS33 [get_ports {hi_in[*]}]

set_property PACKAGE_PIN R15 [get_ports {hi_out[0]}]
set_property PACKAGE_PIN N13 [get_ports {hi_out[1]}]
set_property IOSTANDARD LVCMOS33 [get_ports {hi_out[*]}]

set_property PACKAGE_PIN T15 [get_ports {hi_inout[0]}]
set_property PACKAGE_PIN T14 [get_ports {hi_inout[1]}]
set_property PACKAGE_PIN R16 [get_ports {hi_inout[2]}]
set_property PACKAGE_PIN P16 [get_ports {hi_inout[3]}]
set_property PACKAGE_PIN P15 [get_ports {hi_inout[4]}]
set_property PACKAGE_PIN N16 [get_ports {hi_inout[5]}]
set_property PACKAGE_PIN M16 [get_ports {hi_inout[6]}]
set_property PACKAGE_PIN M12 [get_ports {hi_inout[7]}]
set_property PACKAGE_PIN L13 [get_ports {hi_inout[8]}]
set_property PACKAGE_PIN K13 [get_ports {hi_inout[9]}]
set_property PACKAGE_PIN M14 [get_ports {hi_inout[10]}]
set_property PACKAGE_PIN L14 [get_ports {hi_inout[11]}]
set_property PACKAGE_PIN K16 [get_ports {hi_inout[12]}]
set_property PACKAGE_PIN K15 [get_ports {hi_inout[13]}]
set_property PACKAGE_PIN J14 [get_ports {hi_inout[14]}]
set_property PACKAGE_PIN J13 [get_ports {hi_inout[15]}]
set_property IOSTANDARD LVCMOS33 [get_ports {hi_inout[*]}]

set_property PACKAGE_PIN M15 [get_ports {hi_aa}]
set_property IOSTANDARD LVCMOS33 [get_ports {hi_aa}]


create_clock -name okHostClk -period 20.83 [get_ports {hi_in[0]}]

set_input_delay -add_delay -max -clock [get_clocks {okHostClk}]  11.000 [get_ports {hi_inout[*]}]
set_input_delay -add_delay -min -clock [get_clocks {okHostClk}]  0.000  [get_ports {hi_inout[*]}]
set_multicycle_path -setup -from [get_ports {hi_inout[*]}] 2

set_input_delay -add_delay -max -clock [get_clocks {okHostClk}]  6.700 [get_ports {hi_in[*]}]
set_input_delay -add_delay -min -clock [get_clocks {okHostClk}]  0.000 [get_ports {hi_in[*]}]
set_multicycle_path -setup -from [get_ports {hi_in[*]}] 2

set_output_delay -add_delay -clock [get_clocks {okHostClk}]  8.900 [get_ports {hi_out[*]}]

set_output_delay -add_delay -clock [get_clocks {okHostClk}]  9.200 [get_ports {hi_inout[*]}]

# LEDs #####################################################################
set_property PACKAGE_PIN H5 [get_ports {led[0]}]
set_property PACKAGE_PIN F3 [get_ports {led[1]}]
set_property PACKAGE_PIN E3 [get_ports {led[2]}]
set_property PACKAGE_PIN H4 [get_ports {led[3]}]
set_property PACKAGE_PIN D3 [get_ports {led[4]}]
set_property PACKAGE_PIN C3 [get_ports {led[5]}]
set_property PACKAGE_PIN H3 [get_ports {led[6]}]
set_property PACKAGE_PIN A4 [get_ports {led[7]}]
set_property IOSTANDARD LVCMOS33 [get_ports {led[*]}]

set_property PACKAGE_PIN K1 [get_ports {cnvPin}]
set_property IOSTANDARD LVCMOS33 [get_ports {cnvPin}]
set_property PACKAGE_PIN E12 [get_ports {tmpPin}]
set_property IOSTANDARD LVCMOS33 [get_ports {tmpPin}]
set_property PACKAGE_PIN K2 [get_ports {tenPin}]
set_property IOSTANDARD LVCMOS33 [get_ports {tenPin}]

set_property PACKAGE_PIN B15 [get_ports {sclkPin}]
set_property IOSTANDARD LVCMOS33 [get_ports {sclkPin}]
set_property PACKAGE_PIN C16 [get_ports {mosiPin}]
set_property IOSTANDARD LVCMOS33 [get_ports {mosiPin}]
set_property PACKAGE_PIN D15 [get_ports {adccsPin}]
set_property IOSTANDARD LVCMOS33 [get_ports {adccsPin}]

#set_property PACKAGE_PIN J1 [get_ports {misoPins}]
#set_property IOSTANDARD LVCMOS33 [get_ports {misoPins}]
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

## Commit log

2023-11-08 Add files via upload
    Add in executables
    [96ch.csv]
2023-11-08 Add files via upload
    Change dir to FlySongExecutables
    [96ch.csv]
2023-11-08 Add files via upload
    Added Eagle Files and Gerbers
    [12_BCKPLN_FPGA_J007922REVB.xlsx, 12_BCKPLN_FPGA_J008340B.brd, 12_BCKPLN_FPGA_J008340B.sch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]
2023-11-08 Create Boards desigend in Eagle PCB 7.7.0
2023-11-08 Added Mechanical Files
    [BatteryBox_J007969-BLK.stl, CameraMountA_J010538.stl, ChamberSupports_LaserCuts_J008340A.dxf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]
2023-11-08 Added full parts list
    [96ChannelRecordingRig.xlsx]
2023-11-13 Add Source Code
    Added FlySong and FPGA source code
    [smpl.csv, sync_rates1.xlsx]
2023-11-13 Delete FlySongExecutables directory
    Redundant directory
    [96ch.csv]
2023-11-13 rename directory
    from FlySong to FlySongExecutablesAndRunFiles
    [96ch.csv]
2023-11-13 Edited 96ch sample file
    Made each name unique and indicative of the cell it is in
    [96ch.csv]
2024-01-04 Add Install Files for Camera Software
2024-05-21 RGB Control updates
    Add RGB serial control connector to backplane
    Add RGB serial control to FPGA firmware and FlySong software
    [12_BCKPLN_FPGA_J007922REVB.xlsx, 12_BCKPLN_FPGA_J008340B.brd, 12_BCKPLN_FPGA_J008340B.sch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]
2024-05-21 Update runtime files and add miniFlySong
    Updated run time files to run the version with serial RGB control
    Added miniFlySong. This design utilizes a small board with a Teensy 4.0 to run FlySong on a single 8 channel board, without the 12 slot Backplane board, Useful for small experiments. Uses a special v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
    [miniFlySongSupport.brd, miniFlySongSupport.dxf, miniFlySong_J010706C.brd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]
2024-05-23 add miniFlySong and rig photos
    [96ChannelRecordingRig.xlsx, WHT_8Chamber_J009584D.ipt, WHT_8Chamber_J009584D.stl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]
2024-05-31 Create FlySongRGBMirrors.dxf
    Laser cut file for FlySong mirrors used with RGB lighting
    [FlySongRGBMirrors.dxf]
2024-05-31 Add mechanical parts to FlySong RGB
    [96ChannelRecordingRig.xlsx, TslotMirrorSupport.stl, tiltedReflectorAligner.stl]
2024-06-03 Add 35mm arena to Fly Song Rig
    35 mm arena uses 7 microphones to record flies in a 35 mm diameter arena. It plugs into the FlySong backplane.
    [3MIC_backplaneREVA.brd, 3MIC_backplaneREVA.sch, 3MIC_backplaneREVA.xlsx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]
2024-07-17 Update BOMs and boards, add miniFlySong photo
    [12_BCKPLN_FPGA_J008340C.brd, 12_BCKPLN_FPGA_J008340C.sch, 96ChannelRecordingRig.xlsx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]
2024-08-19 Backplane BOM, FPGA RGB control error
    Backplane BOM had incorrect parts for the BNC and Battery connector
    Fixed spelling error in Eagle note
    There were errors when the backplane controlled an RGB display via serial control. The serial circular buffer was not being filled correctly at wrap around. Code was changed so that the buffer was filled differently, one value per clock, with one increment of the pointer per clock. This seems to fix the problem.
    [96ChannelRecordingRig.xlsx, miniFlySong_J010706C.csv]
2024-10-15 Updates and corrections
    Updated BOM with correct quantities
    Latest FPGA file
    Updated 3D print and laser cut files
    [96ChannelRecordingRig.xlsx, BatteryHolder_J007969.ipt, CameraMountA.ipt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]
2025-01-11 Update BOM, add 3D pdf of rig, add load cover laser cut file fro 12x12 sheet
    [96ChannelRecordingRig.xlsx, LoadCover-12x12sheet.dxf]
2025-01-28 update print files and BOM
    Change diffuser to 1/8" not 1/16"
    [96ChannelRecordingRig.xlsx, BLKbackplaneBracketMid.ipt, CameraMountA_J010538.ipt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]
2025-01-30 Update silkscreen to reflect board rev D and correct rev date, rename U19 to U1
    [8MIC_ximpedance_J007901D.sch]

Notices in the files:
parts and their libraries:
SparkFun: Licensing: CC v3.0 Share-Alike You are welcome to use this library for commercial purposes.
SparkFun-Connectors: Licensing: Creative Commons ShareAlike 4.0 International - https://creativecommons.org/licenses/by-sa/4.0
